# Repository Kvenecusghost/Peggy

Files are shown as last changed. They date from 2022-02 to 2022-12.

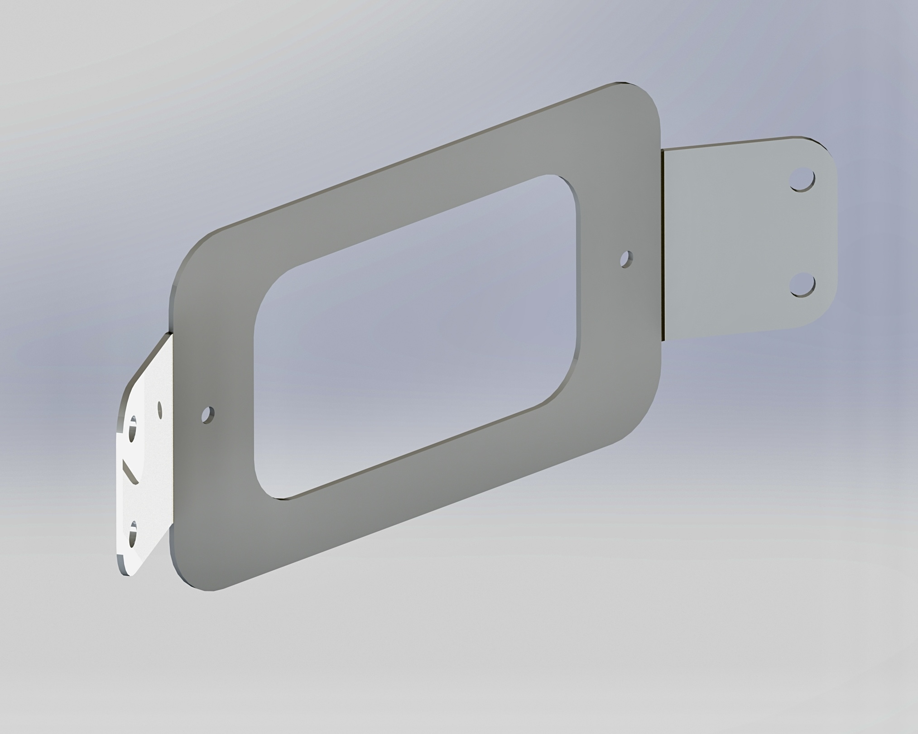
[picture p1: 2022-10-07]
Hardware_fabrication/Tracker/v2.0 19.03.2022/3d/Скриншоты/IMG_4819.JPG

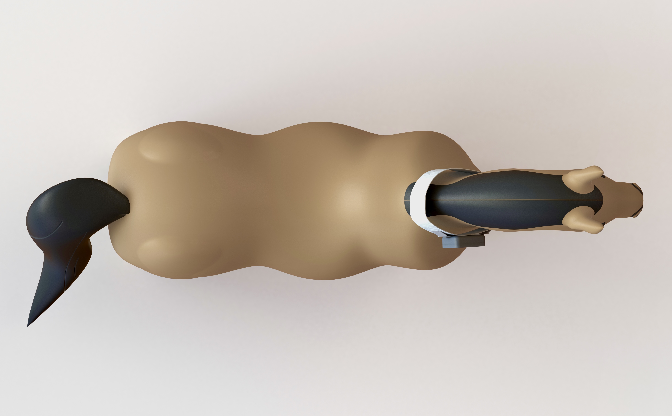
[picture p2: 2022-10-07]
Hardware_fabrication/Tracker/v2.0 19.03.2022/3d/Скриншоты/IMG_4811.JPG

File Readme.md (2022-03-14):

# Структура проекта

doc - папка для хранения документации. 

- Tracker - папка с документами для ПП трекера
- Receiver - папка с документами для ПП приёмника
- Repeater - папка с документами для ПП репитера 

Hardware - папка для хранения исходных файлов проектов ПП в ПО Altium

- Tracker - папка с проектом для ПП трекера
- Receiver - папка с проектом для ПП приёмника
- Repeater - папка с проектом для ПП репитера 

Hardware_release - папка для хранения выходных документов ПП.

- Tracker - папка с производственными файлами для ПП трекера   
- Receiver - папка с производственными файлами для ПП приёмника
- Repeater - папка с производственными файлами для ПП репитера 

   Для каждой версии создаётся отдельная папка. В названии указывается номер версии ПП и дата выгрузки файлов.
   
Software - папка с исходными файлами ПО

- Tracker - папка с исходными файлами ПО треккера Peggy

Software_release - папка скомплированных прошивок

- Tracker - папка скомпилированных прошивок для треккера Peggy
- Receiver - папка скомпилированных прошивок для приёмника Peggy
- Repeater - папка скомпилированных прошивок для репитера Peggy

   Для каждой версии создаётся отдельная папка. В названии указывается номер версии ПО и дата компиляции.

3d - папка для 3d моделей, чертежей и других файлов для корпусирования

- Tracker - папка для корпусов треккера Peggy
- Receiver - папка для корпусов приёмника Peggy
- Repeater - папка для корпусов передатчика Peggy

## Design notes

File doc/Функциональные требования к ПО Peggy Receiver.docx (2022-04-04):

# 1 ВВЕДЕНИЕ

Peggy Receiver создаётся для получения геолокационных данных о местоположении крупного скота во время выпаса.

## 1.1 Назначение данного документа

Данный документ определяет требования к встраиваемому программному обеспечению системы Peggy Receiver, для исключения ошибок проектирования программного обеспечения, которые могут вызвать систематические отказы. Данный документ является входной информацией для документов «Архитектура программного обеспечения», «Описание программного обеспечения» и для непосредственной реализации программного обеспечения.

## 1.2 Термины, определения и сокращения

Встраиваемое программное обеспечение - программное обеспечение, непосредственно реализующее функции управления устройством, как правило, записанное в энергонезависимое ПЗУ устройства и заменяемое с помощью специальных программно-аппаратных средств.

ПО – программное обеспечение.

МК – микроконтроллер.

ТЗ – техническое задание.

ЦСМ – централизованная система мониторинга.

## 1.3 Рекомендации к ознакомлению

Перед ознакомлением данного документа рекомендуется изучить техническое задание (Техническое задание Peggy Receiver) и технический проект (Технический проект Peggy Receiver) на устройство Peggy Receiver, а также следующие ссылки:

- RAK3172 Datasheet;

- HC-08 Datasheet;

- STM32WLE5CC Datasheet;

- STM32WLE5CC Reference Manual

## 1.4 Назначение разработки

ПО разрабатывается для RAK3172 на базе микроконтроллера STM32WLE5CC.

Структурная схема устройства Peggy Receiver представлена на рисунке 1.

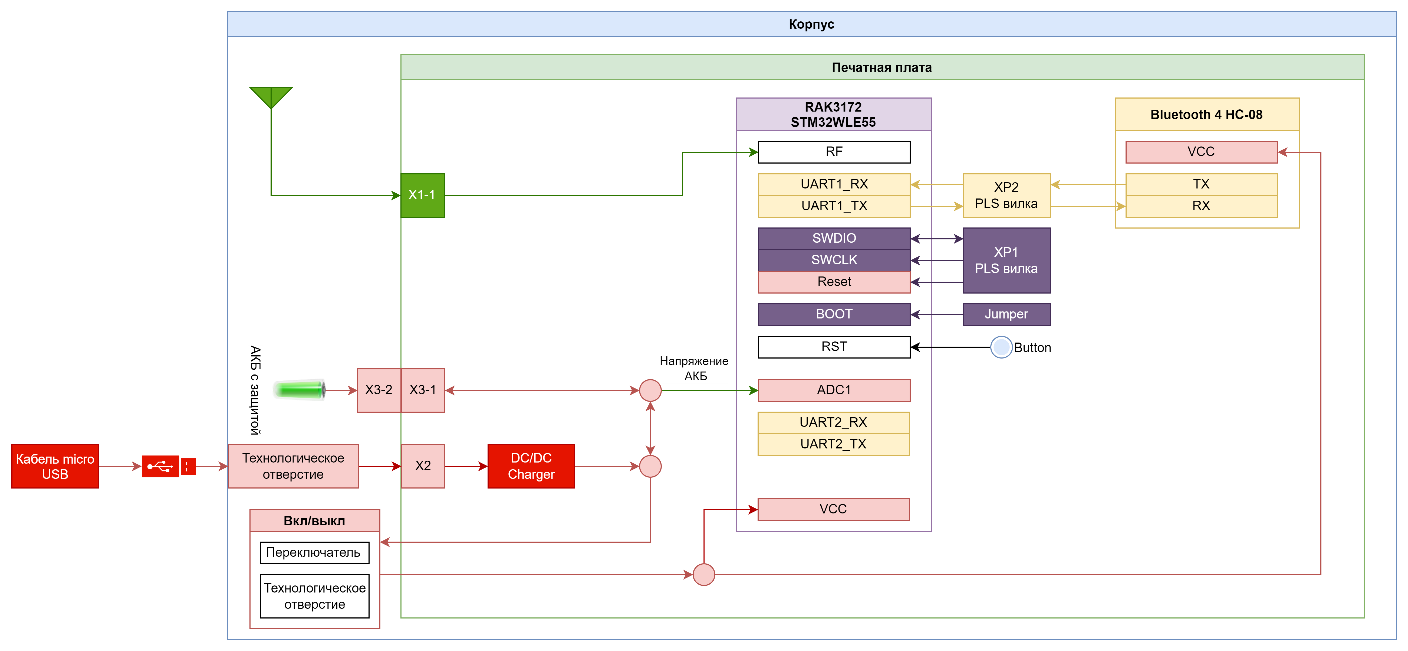
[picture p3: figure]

Рисунок 1.1 - Структурная схема устройства Peggy Receiver

МК STM32WLE5C содержит в себе ядро ARM Cortex M4 и радио интерфейс LoRa. МК содержит 256КБ Flash памяти программ и 64КБ ОЗУ, 12 битный АЦП и UART интерфейсы.

# 2 Общие характеристики устройства

Задачей системы является приём GPS координат по LoRa интерфейсу и передача данных по Bluetooth интерфейсу на смартфон. Первоначальный запуск системы осуществляется с участием человека, а дальнейшая работа происходит автоматически.

## 2.1 Функции, выполняемые устройством

Измерение заряда АКБ – заряд АКБ измеряется при помощи АЦП МК STM32WLE5CC.

Приём данных по интерфейсу LoRa – данные о местоположении принимаются по интерфейсу LoRa МК STM32WLE5CC.

Отправка данных на смартфон – отправка данных на смартфон осуществляется по интерфейсу Bluetooth.

## 2.2 Основные ограничения

1) Язык программирования C. Ограничение среды программирования применяемых МК.

## 2.3 Зависимости и влияние

Среда разработки STM32 Cube IDE или любая другая совместимая с микроконтроллерами STM32.

Для программирования МК может быть применен любой софт поддерживающий программатор ST-Link v2.

# 3 Определение требований

## 3.1 Требования к функционированию МК1

### 3.1.1 Измерение напряжения АКБ

Peggy Receiver должен иметь возможность измерять заряд АКБ. Заряд АКБ должен измеряться при помощи АЦП на порту ADC1. Отсчеты АЦП должны преобразовываться в десятые доли от максимального заряда.

### 3.1.2 Приём данных по интерфейсу LoRa

МК должен иметь возможность принимать данные по интерфейсу LoRa. В качестве полезной нагрузки должны приниматься следующие данные: уникальный ID Peggy Tracker, номер посылки, широта, долгота. Формат посылки представлен на рисунке ниже:

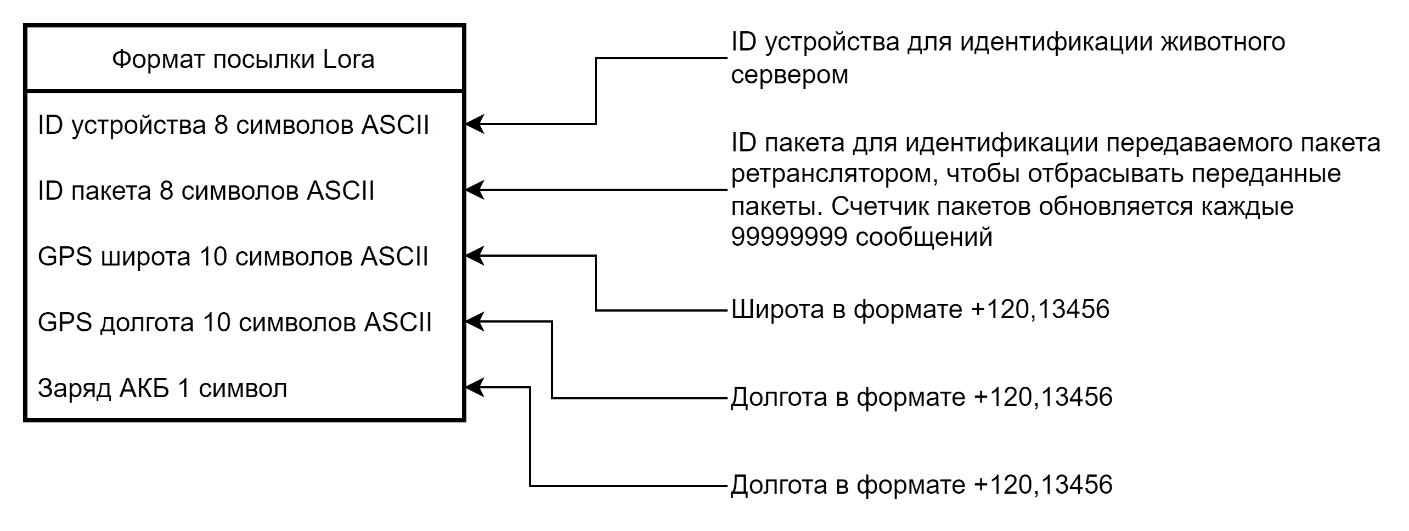
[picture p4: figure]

Рисунок 3.1. Формат посылки LoRa.

Кроме стандартных пакетов данных по интерфейсу LoRa должен приниматься пакет-тревога Peggy Tracker. Формат данной посылки представлен на рисунке ниже:

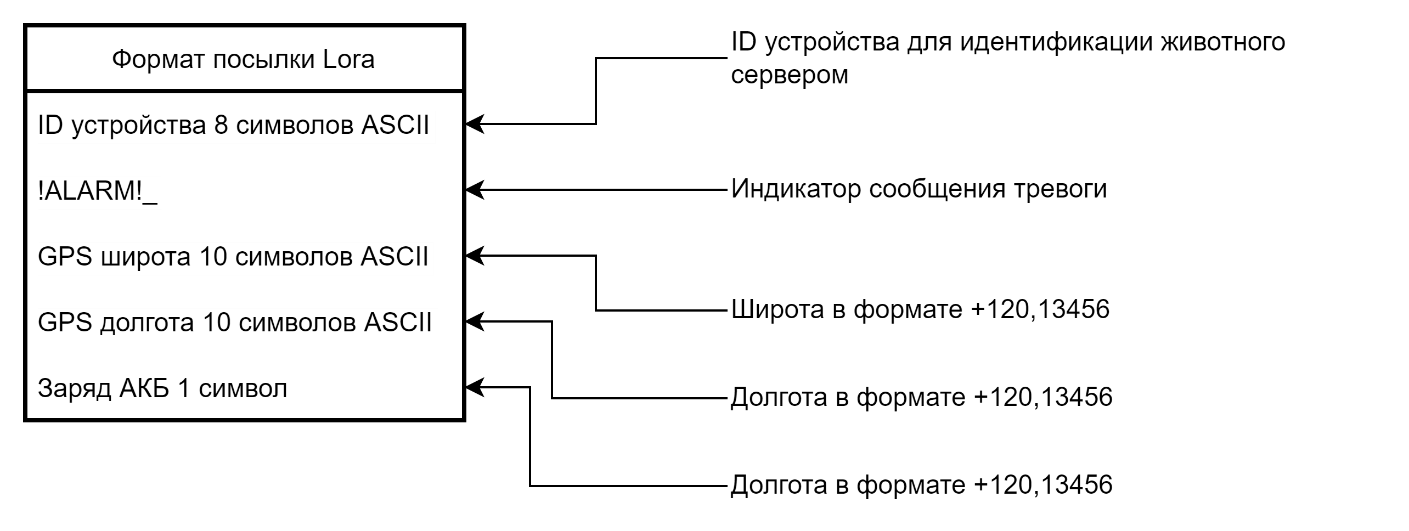
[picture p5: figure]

Рисунок 3.2. Формат посылки тревоги

## 3.2 Требования к интерфейсам

UART

Последовательный асинхронный интерфейс UART.

Интерфейс для взаимодействия с модулем HC-08.

Аналоговый вход

Интерфейс для преобразования аналоговых сигналов в цифровые. Предназначен для измерения постоянного напряжения АКБ.

Динамический диапазон входного напряжения 0~3,3В.

# 4 ЛИСТ РЕГИСТРАЦИИ ИЗМЕНЕНИЙ

№ п/п | Пункт и вносимое изменение | Ф.И.О. внесшего изменения | Подп. | Дата
1 | Инициация | Байгуаныш С. | | 04.04.2022г.

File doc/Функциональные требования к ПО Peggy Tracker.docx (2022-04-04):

# 1 ВВЕДЕНИЕ

Peggy Tracker создаётся для отслеживания геолокации крупного скота во время выпаса

## 1.1 Назначение данного документа

Данный документ определяет требования к встраиваемому программному обеспечению системы Peggy Tracker, для исключения ошибок проектирования программного обеспечения, которые могут вызвать систематические отказы. Данный документ является входной информацией для документов «Архитектура программного обеспечения», «Описание программного обеспечения» и для непосредственной реализации программного обеспечения.

## 1.2 Термины, определения и сокращения

Встраиваемое программное обеспечение - программное обеспечение, непосредственно реализующее функции управления устройством, как правило, записанное в энергонезависимое ПЗУ устройства и заменяемое с помощью специальных программно-аппаратных средств.

ПО – программное обеспечение.

МК – микроконтроллер.

ТЗ – техническое задание.

ID устройства – уникальный 4-ёх байтный идентификатор устройства. ID прописывается на стадии загрузки программы в устройство и указывается на печатной плате и корпусе устройства по окончании сборки.

ЦСМ – централизованная система мониторинга.

## 1.3 Рекомендации к ознакомлению

Перед ознакомлением данного документа рекомендуется изучить техническое задание (Техническое задание Peggy Tracker) и технический проект (Технический проект Peggy Tracker) на устройство Peggy Tracker, а также следующие ссылки:

- RAK3172 Datasheet;

- u-blox M8C Datasheet;

- STM32WLE5CC Datashet;

- STM32WLE5CC Reference Manual

## 1.4 Назначение разработки

ПО разрабатывается для RAK3172 на базе микроконтроллера STM32WLE5CC.

Структурная схема устройства Peggy Tracker представлена на рисунке 1.

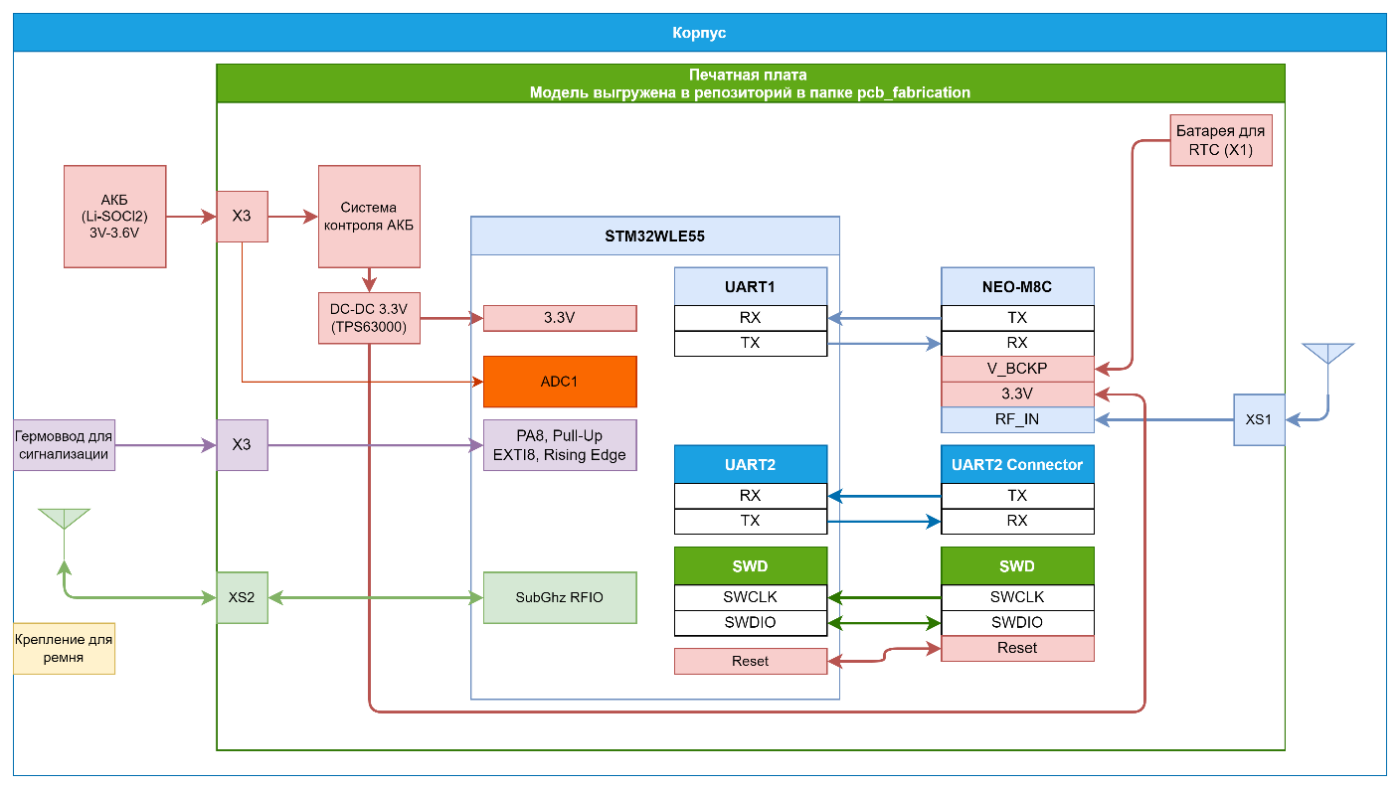
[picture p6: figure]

Рисунок 1.1 - Структурная схема устройства Peggy Tracker

МК STM32WLE5C содержит в себе ядро ARM Cortex M4 и радио интерфейс LoRa. МК содержит 256КБ Flash памяти программ и 64КБ ОЗУ, 12 битный АЦП и UART интерфейсы.

# 2 Общие характеристики устройства

Задачей системы является фиксация GPS координат и отправка по LoRa интерфейсу. Первоначальный запуск системы осуществляется с участием человека, а дальнейшая работа происходит автоматически.

## 2.1 Функции, выполняемые устройством

Измерение заряда АКБ – заряд АКБ измеряется при помощи АЦП МК STM32WLE5CC.

Сигнализация – обнаружение нарушения целостности ошейника.

Геолокация – производится при помощи модуля NEO-M8C. МК STM32WLE5CC должен считывать данные о геопозиции из модуля NEO-M8C по интерфейсу UART1.

Отправка данных по LoRa – данные о местоположении должны быть отправлены по LoRa интерфейсу.

## 2.2 Основные ограничения

1) Язык программирования C. Ограничение среды программирования применяемых МК.
2) Определение местоположения с точностью до 100м на открытой местности.

## 2.3 Зависимости и влияние

Среда разработки STM32 Cube IDE или любая другая совместимая с микроконтроллерами STM32.

Для программирования МК может быть применен любой софт поддерживающий программатор ST-Link v2.

# 3 Определение требований

1) Программный код должен гарантированно выполняться за определённое время.
1) Необходимо обеспечить отправку данных с возможностью изменения периода передачи
2) Необходимо обеспечить минимальное энергопотребление микроконтроллером и модулем NEO M8C.

## 3.1 Требования к функционированию МК

### 3.1.1 Измерение напряжения АКБ

Peggy Tracker должен иметь возможность измерять заряд АКБ. Заряд АКБ должен измеряться при помощи АЦП на порту ADC1. Отсчеты АЦП должны преобразовываться в десятые доли от максимального заряда.

### 3.1.2 Геолокация

Функция геолокации должна обеспечивать данные о местоположении устройства в виде координат GPS. В рамках данной функции МК должен считывать широту и долготу по UART из модуля NEO M8C. Также МК должен переводить и выводить из режима энергосбережения модуль NEO M8C.

### 3.1.3 Передача данных по интерфейсу LoRa

МК должен иметь возможность отправлять данные по интерфейсу LoRa. Данные должны отправляться в формате, обеспечивающем максимальный радиус передачи (до 10км). В качестве полезной нагрузки должны отправляться следующие данные: уникальный ID устройства, номер посылки, широта, долгота. Формат посылки представлен на рисунке ниже:


Рисунок 3.1. Формат посылки LoRa.

### 3.1.4 Сигнализация

Порт PA8 МК подключен к питанию через подтягивающий резистор. Когда ошейник застегнут на шее животного порт PA8 подключается к нулю при помощи интегрированного в ошейник кабеля. МК должен выходить из режима сна и отправлять сообщение по интерфейсу LoRa с тревогой, если на ножке PA8 появится высокий уровень напряжения. Формат посылки представлен на рисунке ниже:


Рисунок 3.2. Формат посылки тревоги

## 3.2 Требования к интерфейсам

Цифровой вход

Интерфейс для получения бинарной информации от внешних устройств (Сигнализация).

Время обработки информации не более одного цикла программы.

Наличие чётких логических уровней.

UART

Последовательный асинхронный интерфейс UART.

Интерфейс для взаимодействия с модулем NEO M8C.

Аналоговый вход

Интерфейс для преобразования аналоговых сигналов в цифровые. Предназначен для постоянного напряжения АКБ.

Динамический диапазон входного напряжения 0~3,3В.

# 4 ЛИСТ РЕГИСТРАЦИИ ИЗМЕНЕНИЙ

№ п/п | Пункт и вносимое изменение | Ф.И.О. внесшего изменения | Подп. | Дата
1 | Инициация | Байгуаныш С. | | 01.04.2022г.

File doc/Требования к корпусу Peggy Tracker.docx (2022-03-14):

# Технические требования к корпусу изделия Peggy Tracker

## Состав изделия

Изделие состоит из следующих частей:

- ошейник с креплением для корпуса;
- корпус;
- аккумуляторная батарея;
- печатная плата.

## Конструктивные требования к корпусу с ошейником

Общие требования к внешнему виду устройства: устройство небольших размеров с компактным дизайном корпуса, корпус должен быть обтекаемым, без заостренных углов, так как по условиям ТЗ будет плотно прилегать к телу животного (лошади), за счет чего устройство держит оптимальную температуры для работы, также корпус должен быть удобным в исполнений и использовании, пример рис. 1 и 2.

При этом должны учитываться следующие требования:

- максимальные габаритные размеры (ШхДхГ): 100х100х25 мм.;
- исполнение моноблочное с возможностью открытия (для смены батареи) с креплением на ошейник;
- эргономика: наглядность и понятность функциональных частей, удобство использования устройства;
- цветофактурное решение: гладкая поверхность, темные тона;
- требуется прочный пластик, пример ABS;
- вес не более 1,5 кг;
- ширина ошейника не более 100 мм.;
- устройство должно быть защищено от пыли и влаги по стандарту IP68;
- аппаратура должна обладать высокой противокоррозионной стойкостью;
- в течение периода его эксплуатации не должно быть коррозионных повреждений, приводящих к снижению тактико-технических характеристик;
- устройство должно быть устойчиво к ударам и тряске.

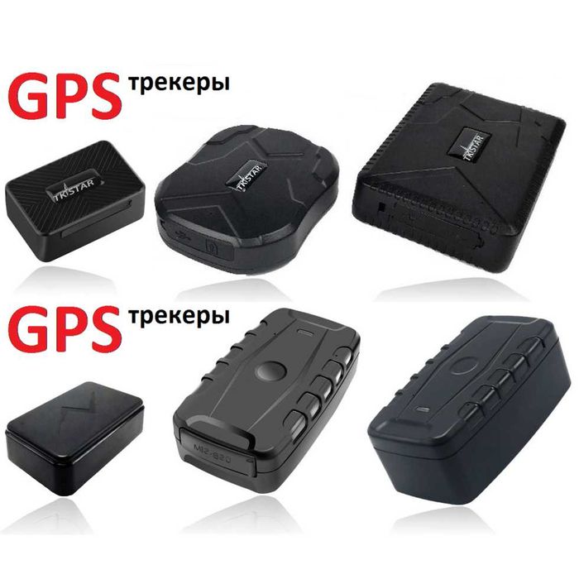
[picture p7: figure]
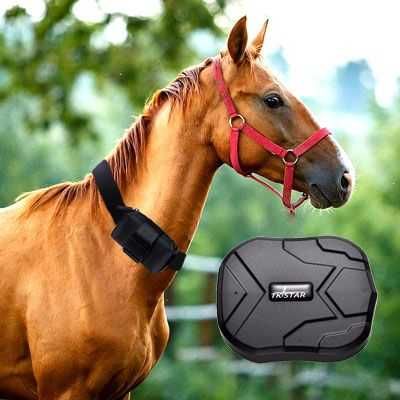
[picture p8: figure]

Рис. 1 – Пример GPS датчика | Рис. 2 – Пример крепления GPS датчика с ошейником на лошади

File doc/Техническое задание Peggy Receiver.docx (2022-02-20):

СОДЕРЖАНИЕ

# 1 НАИМЕНОВАНИЕ, ОСНОВАНИЕ, РАЗРАБОТЧИК И СРОК РАЗРАБОТКИ

1.1 Приёмнику системы отслеживания геолокации лошадей присваивается рабочее название Peggy Receiver
1.2 Принятые сокращения:

МК – микроконтроллер

АКБ – аккумуляторная батарея

ЦСМ – центральная система мониторинга

ЗУ – зарядное устройство

# 2 ЦЕЛЬ РАЗРАБОТКИ, НАИМЕНОВАНИЕ И ОБЛАСТЬПРИМЕНЕНИЯ

2.1 Цель разработки: обеспечение доставки данных о геолокации лошадей.
2.2 Полное наименование разработки – «Приёмник системы отслеживания геолокации лошадей Peggy Receiver» (далее по тексту «Peggy Receiver»).
2.3 Peggy Receiver предназначен для приёма сообщений получаемых от Peggy Tracker по интерфейсу LoRa и отправки данных на смартфон пользователя.
2.4 Областью применения Peggy Receiver являются коневодческие пастбища со свободным выгоном.

# 3 ТЕХНИЧЕСКИЕ ТРЕБОВАНИЯ

# 3.1 Состав изделия

3.1.1 В состав Peggy Receiver в общем случае должны входить:

- Плата Peggy Receiver;

- Корпус Peggy Receiver;

- АКБ;

- ЗУ;

- Паспорт Peggy Receiver.

# 3.2 Требования назначения

3.2.1 Peggy Receiver должен быть разработан для коневодческих пастбищ со свободным выгоном не оснащенным источниками электрического тока.
3.2.2 Peggy Receiver должен включать:

а) Блок микроконтроллера (БМК) – предназначенный для:

- Взаимодействия с блоком связи дальнего действия (БСДД);

- Взаимодействие с блоком связи ближнего действия (БСБД);

- Хранение базы принятых сообщений;

- Работы часов реального времени;

б) Блок связи дальнего действия – предназначенный для приёма данных о геолокации по беспроводному каналу LoRa.

в) Блок связи ближнего действия – предназначен для взаимодействия со смартфоном пользователя.

г) Блок управления питанием (БУП)– предназначенный для:

- Обеспечения питанием всех блоков ЛВМ;

- Управления зарядом/разрядом АКБ.

3.2.3 Упрощенная структурная схема Peggy Receiver приведена в приложении А.

# 3.3 Требования к функциональной совместимости

3.3.1 Peggy Receiver должен быть совместим с системой отслеживания местоположения лошадей Peggy.
3.3.2 Корпус Peggy Receiver должен иметь небольшие габариты для обеспечения мобильности.
3.3.3 Peggy Receiver должен иметь возможность заряжаться от ЗУ через разъём стандарта micro-USB.
3.3.4 Peggy Receiver должен иметь СИД для индикации включения и процесса передачи пакетов LoRa.
3.3.5 В качестве радио модуля дальнего действия должен быть использован модуль RAK3172 с рабочей частотой 868МГц.
3.3.6 В качестве радио модуля ближнего действия должен быть использован модуль совместимый со стандартом Bluetooth 4.2 и выше.
3.3.7 Радиообмен сигналами может происходить в открытом виде.

# 3.4 Требования стойкости к внешним воздействиям

3.4.1 По воздействию климатических факторов при эксплуатации Peggy Receiver, должен относиться к классу, в соответствии с Таблицей 1, и быть устойчивым к воздействию климатических факторов в соответствии с ГОСТ 15150-69.

Таблица 1– Классификация оборудования по климатическим факторам

Наименование оборудования | Климатическое исполнение по ГОСТ 15150 | Виды и нормы воздействий климатических факторов
| | Верхнее значение рабочей температуры, С | Верхнее значение предельной рабочей температуры, С | Нижнее значение рабочей температуры, С | Нижнее значение предельной рабочей температуры, С | Характер изменения температуры предельной рабочей | Верхнее значение относительной влажности воздуха, % при температуре 25°С
Peggy Receiver | ТпПр1 | +50 | +60 | -10 | -10 | Постепенное | 98

3.4.2 Peggy Receiver должен быть устойчивым к воздействию механических нагрузок в соответствии с таблицей 2.

Таблица 2 – Классификация оборудования по механическим факторам

Наименование оборудования | Диапазон частот, Гц | Виды и нормы воздействий механических факторов
| | Вибрация
| | Амплитудное значение ускорения, м/с, в направлении воздействия
| | Вертикальном | Горизонтальном
Peggy Receiver | 1-55 | 2 | 2

3.4.3 Степень защиты, обеспечиваемая корпусом, по ГОСТ 14254– не менее IP54.
3.4.4 Peggy Receiver должен быть стойким к воздействию электромагнитных помех с критерием функционирования «B» и соответствовать ГОСТ 30804.6.1.

# 3.5 Требования надежности, готовности и ремонтопригодности

3.5.1 Средняя наработка Peggy Receiver (включая ПО) на отказ не менее 48ч (2 дня) непрерывной работы.
3.5.2 Peggy Receiver должен функционировать в непрерывном длительном режиме.
3.5.3 Средний срок службы до списания не менее 10 лет.
3.5.4 Среднее время восстановления работоспособного состояния не более 40 мин.

# 3.6 Требования безопасности

# 3.6.1 Требования к электробезопасности

3.6.1.1 По электробезопасности оборудование Peggy Receiver должен относиться к II классу по ГОСТ МЭК 61140.
3.6.1.2 Электрическая изоляция электрических цепей Peggy Receiver должна соответствовать требованиям ГОСТ Р МЭК 60664.1-2012.
3.6.1.3 Peggy Receiver должен эксплуатироваться в соответствии с «Правилами техники безопасности при эксплуатации электроустановок потребителем».

# 3.6.2 Требования к функциональной безопасности

3.6.2.1 Требования к функциональной безопасности не предъявляются.

# 3.6.3 Требования к пожарной безопасности

3.6.3.1 Применяемые материалы должны быть трудногорючими по ГОСТ 12.1.044.
3.6.3.2 Уровень обеспечения пожарной безопасности людей в соответствии с п.1.2 ГОСТ 12.1.004.

# 3.7 Требования эргономики и технической эстетики

    3.7.1 Эргономика и техническая эстетика Peggy Receiver должна соответствовать ГОСТ 20.39.108.
    3.7.2 Peggy Receiver должен работать в полностью автоматическом режиме. Обслуживающий персонал должен участвовать только в устранении неисправностей и отказов.
    3.7.3 Конструкция Peggy Receiver должна обеспечивать удобный монтаж.
    3.7.4 Устройства визуального контроля должны обеспечивать четкое и однозначное восприятие информации обслуживающим персоналом.
    3.7.5 Надписи должны иметь хорошо читаемые символы и быть контрастными.
    3.7.6 Металлические детали должны иметь защитные антикоррозионные покрытия (за исключением деталей, выполняющих функцию теплоотвода).
    3.7.7 Металлические детали, не имеющие гальванических покрытий, должны иметь лакокрасочные покрытия.

# 3.8 Требования к эксплуатации, хранению, удобству технического обслуживания и ремонта

# 3.8.1 Требования к условиям эксплуатации

  3.8.1.1 Технически Peggy Receiver должен быть реализован без использования оборудования, требующего регулярной периодической замены.
  3.8.1.2 Окружающая среда не взрывоопасная.
  3.8.1.3 Гарантийный срок эксплуатации Peggy Receiver должен быть не менее 1 года.

# 3.8.2 Требования к хранению

  3.8.2.1 Условия хранения должны соответствовать в части воздействия климатических факторов «5» (ОЖ4) по ГОСТ 15150.
  3.8.2.2 Гарантийный срок хранения 1 год.

# 3.8.3 Требования к техническому обслуживанию

  3.8.3.1 БМК должен иметь выводы для подключения к нему программатора внутри корпуса.
  3.8.3.2 БМК должен иметь выводы, позволяющие сбросить Peggy Receiver на настройки по умолчанию.
  3.8.3.3 БМК должен иметь собственные часы реального времени.
  3.8.3.4 БМК должен иметь встроенные источники электроэнергии для питания часов реального времени, рассчитанные на весь срок службы Peggy Receiver.

# 3.8.4 Требование к ремонтопригодности

  3.8.4.1 На месте эксплуатации Peggy Receiver должен восстанавливаться путем замены на новый.

# 3.9 Требования транспортабельности

3.9.1 Условия транспортирования должны соответствовать в части воздействия:

- механических факторов – группе «Ж» по ГОСТ 23216;

- климатических факторов – группе «5» (ОЖ4) по ГОСТ 15150.

# 3.10 Требования безопасности и охраны здоровья

  3.10.1 Общие требования безопасности должны соответствовать ГОСТ 12.2.007.0.
  3.10.2 При производстве должны выполняться требования техники безопасности по ГОСТ 12.3.008.
  3.10.3 Обеспечение специальной защитной одеждой, средствами индивидуальной защиты ног (специальная обувь) и другими предохранительными средствами согласно требованиям ГОСТ 12.4.011 и ГОСТ 12.4.103.
  3.10.4 Санитарно-гигиенические требования рабочей зоны должны соответствовать ГОСТ 12.1.005.
  3.10.5 Общие требования пожарной безопасности в производственных помещениях должны соответствовать Техническому регламенту «Общие требования к пожарной безопасности» и ГОСТ 12.1.004.

# 3.11 Требования стандартизации, унификации и каталогизации

  3.11.1 Комплектующие изделия Peggy Receiver должны быть серийно производимые.
  3.11.2 Должна быть разработана карта замены, допускающая замену элементов одной серии или производителя на изделия другой серии или производителя.

# 3.12 Требования технологичности

  3.12.1 Обеспечить технологичность Peggy Receiver в соответствии с ГОСТ 14.201.
  3.12.2 Запуск Peggy Receiver должен производиться в соответствии с разработанным технологическим процессом запуска на Peggy Receiver.

# 3.13 Конструктивные требования

  3.13.1 Конструкция Peggy Receiver должна обеспечивать:

- удобство эксплуатации изделия;

- индикацию работоспособности в процессе эксплуатации.

# 3.14 Требования охраны окружающей среды

  3.14.1 Контроль вредных выбросов при производстве Peggy Receiver должен производиться по ГОСТ 17.2.3.02.
  3.14.2 ПДК загрязняющих веществ в атмосферном воздухе должно быть в соответствии с ГН 2.1.6.1338-03.

# 3.15 Требования к утилизации

  3.15.1 Перед утилизацией производится разукомплектование и демонтаж комплектующих изделий в соответствии с ведомостью оценки и технического состояния, представляемой вместе с актом на списание.
  3.15.2 После снятия с эксплуатации, изделия не представляют опасности для жизни, здоровья людей и окружающей среды.
  3.15.3 Утилизация по ГОСТ Р 53692.

# 4 ТЕХНИКО-ЭКОНОМИЧЕСКИЕ ТРЕБОВАНИЯ

4.1 Себестоимость Peggy Receiver не должна превышать 50000тг.
4.2 Предполагаемый объем выпуска не менее 10шт.
4.3 Экономический эффект достигается за счет сокращения фактов хищения и утери лошадей.

# 5 ТРЕБОВАНИЯ К ВИДАМ ОБЕСПЕЧЕНИЯ

# 5.1 Требования к метрологическому обеспечению

  5.1.1 В качестве средств измерений и контроля параметров при проверке должны использоваться средства измерений и контроля общего применения.
  5.1.2 Должен быть разработан перечень средств измерений и контроля.
  5.1.3 Годность указанных средств должна быть подтверждена сопроводительными документами или клеймами, и они должны быть аттестованы или поверены в установленном порядке.

# 5.2 Требования к диагностическому обеспечению

  5.2.1 Должна производиться диагностика и контроль следующих параметров:

- уровень заряда АКБ

- сообщения за последние 24 часа

  5.2.2 Peggy Receiver должен иметь возможность принимать данные по беспроводному интерфейсу LoRa.
  5.2.3 В Peggy Receiver должна быть возможность смены радиоканалов.
  5.2.4 Полученный пакет должен отправляться в смартфон по Bluetooth интерфейсу не позже, чем через 2 секунды.

# 5.3 Требования к нормативно-техническому обеспечению

  5.3.1 На Peggy Receiver должна быть разработана следующая документация:

- принципиальные схемы;

- монтажные схемы;

- руководство по эксплуатации;

- сводная ведомость;

- методика испытаний;

- программная документация;

Документация должна быть выполнена на русском языке.

# 5.4 Требования к математическому, программному и информационно-лингвистическому обеспечению

  5.4.1 Для БМК в составе Peggy Receiver необходимо разработать встраиваемое программное обеспечение.
  5.4.2 Программное обеспечение БМК в составе Peggy Receiver должно соответствовать ГОСТ Р 51904.
  5.4.3 К встраиваемому программному обеспечению предъявляются следующие требования:

- цикл разработки и документирование ПО должен осуществляться по ГОСТ Р 51904;

- должны быть произведены испытания программного обеспечения.

  5.4.4 Вся представляемая и выводимая информация должна быть на русском языке.

# 6 ТРЕБОВАНИЯ К СЫРЬЮ, МАТЕРИАЛАМ И КОМПЛЕКТУЮЩИМ ИЗДЕЛИЯМ

6.1 Применяемые комплектующие изделия и материалы должны быть допущены к применению на территории стран Таможенного союза.
6.2 Подлежащие обязательной сертификации комплектующие изделия и материалы должны иметь действующие на территории стран Таможенного союза сертификаты.

# 7 ТРЕБОВАНИЯ К МАРКИРОВКЕ И УПАКОВКЕ

7.1 Маркировка и упаковка Peggy Receiver должна соответствовать ТР ТС 003/2011.
7.2 На внешней стороне Peggy Receiver должна быть наклеена самоклеящаяся этикетка, в которой на государственном и русском языках должны быть указаны:

- наименование Peggy Receiver;

- наименование и (или) товарный знак предприятия-изготовителя;

- класс защиты от поражения электрическим током;

- заводской номер Peggy Receiver;

- дата изготовления (месяц и год изготовления);

- надпись «Сделано в Республике Казахстан».

7.3 Маркировка должна быть разборчивой, легко читаемой.
7.4 Маркировка не должна осыпаться, расплываться и выцветать в течение всего срока эксплуатации.
7.5 Транспортная маркировка должна соответствовать ГОСТ 14192.
7.6 На упаковку должна быть наклеена самоклеящаяся этикетка, на которой на государственном и русском языках должны быть указаны:

- наименование Peggy Receiver;

- товарный знак предприятия-изготовителя;

- наименование предприятия-изготовителя;

- юридический адрес предприятия-изготовителя;

- обозначение нормативного документа, в соответствии с которым произведен Peggy Receiver;

- заводской номер Peggy Receiver;

- дата изготовления (месяц и год изготовления);

- масса брутто/нетто в килограммах;

- надпись «Сделано в Республике Казахстан».

7.7 Упаковка должна обеспечивать сохранность при транспортировке и хранении. Упаковку разработать в соответствии с ГОСТ 23216 и требованиями п.3.9 настоящего технического задания.

# 8 ТРЕБОВАНИЯ К СРЕДСТВАМ ОБУЧЕНИЯ

8.1 Так как сборка будет осуществляться силами сотрудников проекта, технологический процесс на сборку не требуется
8.2 Для обучения персонала эксплуатирующей организации должна быть разработана презентация.

# 9 СПЕЦИАЛЬНЫЕ ТРЕБОВАНИЯ

# 9.1 Требования к патентной чистоте и патентоспособности

9.1.1 Требования к патентной чистоте в отношении Peggy Receiver не предъявляются.

# 9.2 Требования разработки средств обеспечения испытаний изделия

9.2.1 Для проведения проверки работоспособности Peggy Receiver после изготовления необходимо разработать соответствующий стенд для ОТК.

# 9.3 Требования к сертификации и декларированию

9.3.1 Требований к сертификации и декларированию изделия не предъявляется.

# 10 ЭТАПЫ ВЫПОЛНЕНИЯ РАЗРАБОТКИ

10.1 Этапы разработки согласно ГОСТ Р 15.301-2016.
10.2 Должно быть изготовлено 10 образцов Peggy Receiver для проведения испытаний.
10.3 Необходимо определить место проведения эксплуатационных испытаний.
10.4 Необходимо разработать эксплуатационную документацию.
10.5 После установки и проведения полевых испытаний процесс разработки считается завершенным.

# 11 ПОРЯДОК ВЫПОЛНЕНИЯ И ПРИЕМКИ ЭТАПОВ РАЗРАБОТКИ

11.1 Порядок разработки согласно ГОСТ Р 15.301-2016.
11.2 Изготовленный образец должен пройти эксплуатационные испытания.
11.3 Разрабатываемая документация должна быть выполнена в соответствии с требованиями стандартов Единой системы конструкторской документации.
11.4 Порядок выполнения согласно таблице 3.

Таблица 3 – Порядок выполнения этапов разработки

№ | Наименование | Код
| Реестр документов | PGGRCVR.000ДР
| Техническое задание | PGGRCVR.001ТЗ
| Требования к корпусу | PGGRCVR.002ТК
| Функциональные требования к ПО | PGGRCVR.003ФПО
| Архитектура ПО | PGGRCVR.004АПО
| Технический проект | PGGRCVR.005ТП
| Электрическая принципиальная схема | PGGRCVR.006Э3
| Монтажная схема | PGGRCVR.040Э4
| Схема подключения | PGGRCVR.042Э5
| Сборочный чертеж | PGGRCVR.043СБ
| Паспорт | PGGRCVR.016ПС

# 12 ПРЕДПОЛАГАЕМЫЙ РАЗРАБОТЧИК И ПОЛИГОН ВНЕДРЕНИЯ ПРОДУКЦИИ

12.1 Разработчик Peggy Receiver – АО «КАТУ им. С.Сейфуллина
12.2 Полигон внедрения –

# ПРИЛОЖЕНИЕ А. Упрощенная структурная схема Peggy Receiver

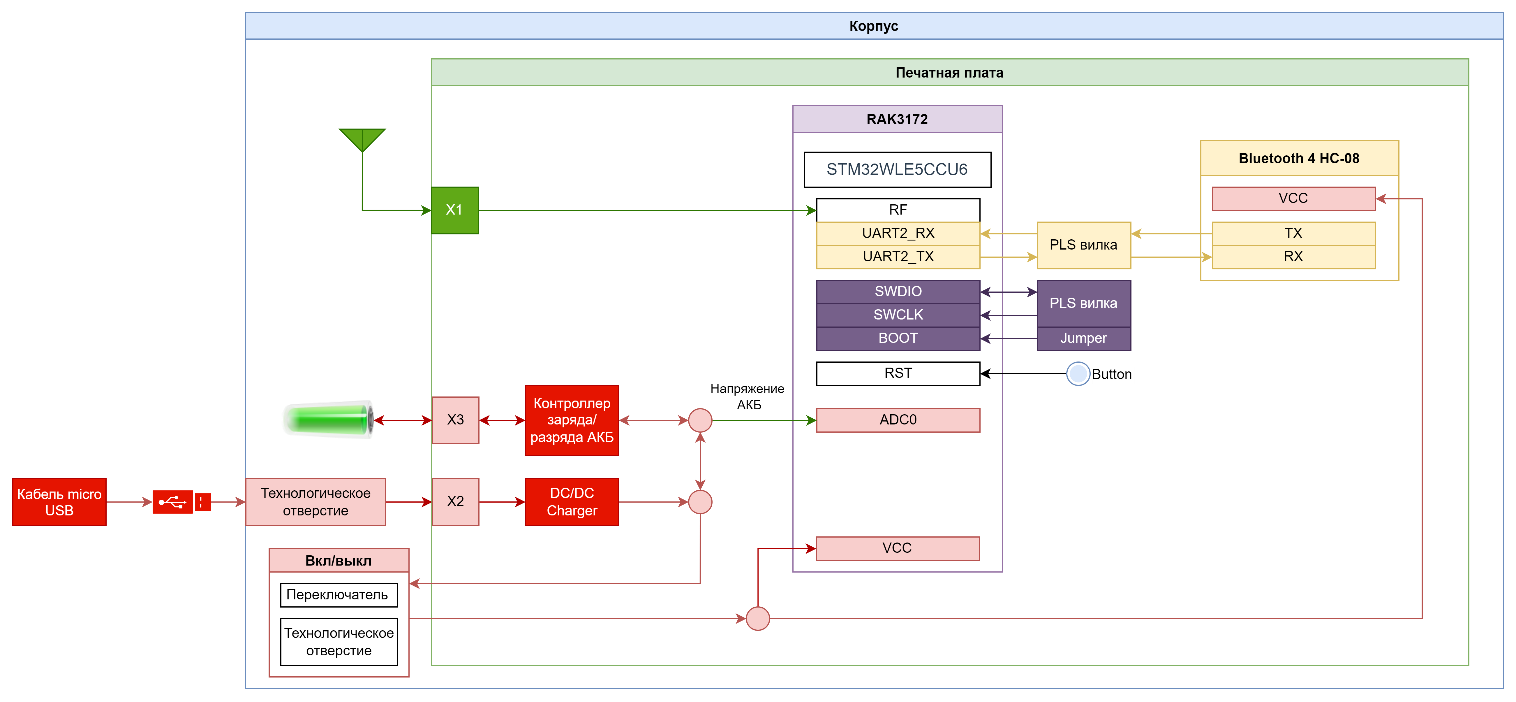
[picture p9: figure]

Рисунок А1 - Упрощенная структурная схема Peggy Receiver

# ПРИЛОЖЕНИЕ Б. Список использованной нормативной документации

1 При разработке настоящего технического задания учитывались требования следующих документов:

- ГОСТ 12.1.004-91 «Система стандартов безопасности труда. Пожарная безопасность. Общие требования»;

- ГОСТ 12.1.005-88 «Система стандартов безопасности труда. Общие санитарно-гигиенические требования к воздуху рабочей зоны»;

- ГОСТ 12.1.044-2018 «Система стандартов безопасности труда. Пожаровзрывоопасность веществ и материалов. Номенклатура показателей и методы их определения»;

- ГОСТ 12.2.007.0-75 «Система стандартов безопасности труда. Изделия электротехнические. Общие требования безопасности»;

- ГОСТ 12.3.008-75 «Система стандартов безопасности труда. Производство покрытий металлических и неметаллических неорганических. Общие требования безопасности»;

- ГОСТ 12.4.011-89 «Система стандартов безопасности труда. Средства защиты работающих. Общие требования и классификация»;

- ГОСТ 12.4.103-83 «Система стандартов безопасности труда. Одежда специальная защитная, средства индивидуальной защиты ног и рук. Классификация»;

- ГОСТ 14.201-83 «Обеспечение технологичности конструкций изделий. Общие требования»;

- ГОСТ 15.012-84 «Система разработки и постановки продукции на производство. Патентный формуляр»;

- ГОСТ 17.2.3.02-2014 «Правила установления допустимых выбросов загрязняющих веществ промышленными предприятиями»;

- ГОСТ 20.39.108-85 «Комплексная система общих технических требований. Требования по эргономике, обитаемости и технической эстетике. Номенклатура и порядок выбора»;

- ГОСТ 14192-96 «Маркировка грузов»;

- ГОСТ 14254-2015 «Степени защиты, обеспечиваемые оболочками (Код IP)».

- ГОСТ 15150-69 «Машины, приборы и другие технические изделия. Исполнения для различных климатических районов. Категории, условия эксплуатации, хранения и транспортирования в части воздействия климатических факторов внешней среды»;

- ГОСТ 18620-86 «Изделия электротехнические. Маркировка»;

-ГОСТ 23216-78 «Изделия электротехнические. Хранение, транспортирование, временная противокоррозионная защита, упаковка. Общие требования и методы испытаний»;

- ГОСТ 30804.6.1-2013 «Устойчивость к электромагнитным помехам технических средств, применяемых в жилых, коммерческих зонах и производственных зонах с малым энергопотреблением»;

- ГОСТ Р 51904-2002 «Программное обеспечение встроенных систем. Общие требования к разработке и документированию»;

- ГОСТ МЭК 61140-2012 «Защита от поражения электрическим током. Общие положения для электроустановок и электрооборудования»;

- Гигиенические нормативы ГН 2.1.6.1338-03 «Предельно допустимые концентрации (ПДК) загрязняющих веществ в атмосферном воздухе населенных мест».

# ЛИСТ РЕГИСТРАЦИИ ИЗМЕНЕНИЙ

№ п/п | Пункт и вносимое изменение | Ф.И.О. внесшего изменения | Подп. | Дата
1 | Инициация | Байгуаныш С.Б. | | 19.02.2022
2 | Вставил доработанную структурную схему | Байгуаныш С.Б. | | 20.02.2022

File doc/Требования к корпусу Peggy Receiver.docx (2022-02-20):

# Технические требования к корпусу изделия Receiver

## Состав изделия

Изделие состоит из следующих частей:

- корпус;
- аккумуляторная батарея;
- антенна;
- печатная плата.

## Конструктивные требования к корпусу Receiver

Общие требования к внешнему виду устройства: устройство небольших размеров сопоставимые с размерами мобильных устройств, корпус должен быть обтекаемым, без заостренных углов, также корпус должен быть удобным в исполнении и использовании, пример рис. 1 и 2.

При этом должны учитываться следующие требования:

- максимальные габаритные размеры (ШхДхГ): 100х150х50 мм.;
- исполнение моноблочное;
- цветофактурное решение: гладкая поверхность, темные тона;
- требуется прочный пластик, пример ABS;
- вес не более 1 кг;
- необходимо предусмотреть различные эксплуатации: в руках, стационарное;
- устройство должно быть защищено от пыли и влаги по стандарту IP68;
- аппаратура должна обладать высокой противокоррозионной стойкостью;
- в течение периода его эксплуатации не должно быть коррозионных повреждений, приводящих к снижению тактико-технических характеристик;
- устройство должно быть устойчиво к ударам и тряске.

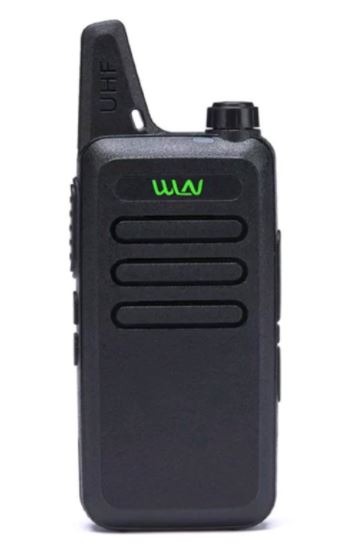
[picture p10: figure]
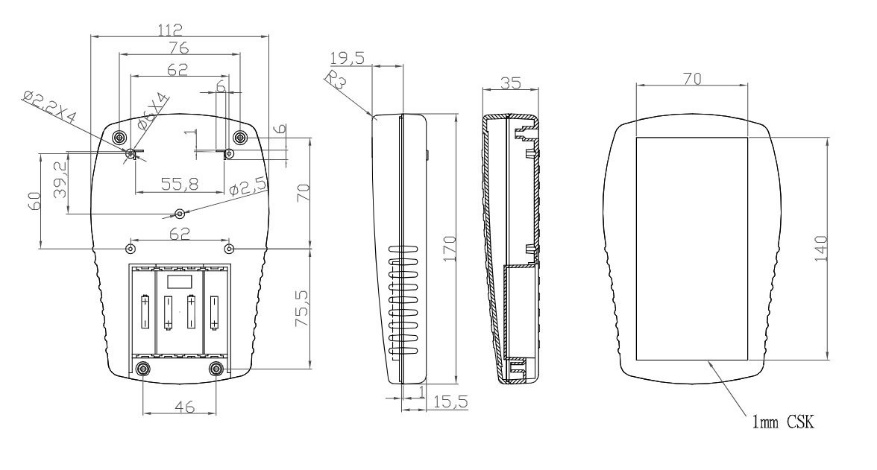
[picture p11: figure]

Рис. 1 – Пример корпуса Receiver | Рис. 2 – Пример корпуса Receiver

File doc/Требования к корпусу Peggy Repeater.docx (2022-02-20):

# Технические требования к корпусу изделия Repeater

## Состав изделия

Изделие состоит из следующих частей:

- корпус;
- антенна;
- аккумуляторная батарея;
- солнечная панель;
- печатная плата.

## Конструктивные требования к корпусу Repeater

Общие требования к внешнему виду устройства: габариты устройства зависит напрямую от выбранного АКБ, корпус должен быть прочным к внешней среде, без заостренных углов, также корпус должен быть удобным в исполнении и использовании, пример рис. 1.

При этом должны учитываться следующие требования:

- минимальные габаритные размеры (ШхДхГ): 150х200х100 мм.;
- исполнение моноблочное с возможностью открытия (для смены батареи);
- цветофактурное решение: гладкая поверхность, темные-светлые тона;
- требуется прочный пластик, пример ABS либо изготовить из металла;
- вес не более 2,5 кг;
- устройство должно быть защищено от пыли и влаги по стандарту IP68;
- аппаратура должна обладать высокой противокоррозионной стойкостью;
- в течение периода его эксплуатации не должно быть коррозионных повреждений, приводящих к снижению тактико-технических характеристик;
- устройство должно быть устойчиво к ударам и тряске.

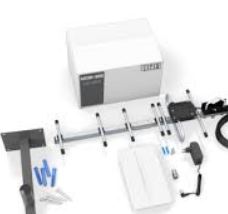
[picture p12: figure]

Рис. 1 – Пример GPS датчика

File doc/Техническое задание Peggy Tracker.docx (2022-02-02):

# Общие сведения;

Наименование: носимое автономное устройство слежения за местоположением скота.

Основание: ТЗ составлено на основе ГОСТ 15.016-2016

Исполнитель:

Сроки выполнения:

# Цель выполнения ОКР;

Цель: разработка законченного устройства слежения за местоположением скота удовлетворяющим всем предъявляемым требованиям согласно настоящему ТЗ.

Назначение: устройство предназначено для отслеживания местоположения лошадей и других животных с целью предотвращения хищения и потери скота. Предполагается применение устройства в условиях отсутствия общедоступных беспроводных сетей связи таких как GSM и Wi-Fi.

Преимущества: увеличение срока функционирования на одном заряде до 3-х месяцев.

# Технические требования к изделию

## Состав изделия

Изделие состоит из следующих частей:

- ошейник с креплением для корпуса
- корпус
- аккумуляторная батарея
- печатная плата

## Требования назначения

- Устройство должно функционировать без подзарядки в течение не менее 90 дней.
- Устройство должно передавать данные о своём местоположении с точностью до 100м на открытой местности.
- Устройство должно передавать данные о своём местоположении не реже 1-го раза в 1 час.
- Устройство должно передавать сигнал аварии в случае нарушения целостности корпуса и/или ошейника
- Устройство должно передавать сигнал аварии в случае пересечения заданных границ
- Устройство должно передавать данные в нелицензируемых частотных диапазонах

## Конструктивные требования

Устройство должно соответствовать следующим конструктивным требованиям:

- габариты не более 100х100х25mm
- исполнение моноблочное с креплением на ошейник
- ширина ошейника не менее 100mm
- вес не более 1.5кг

## Требования электромагнитной совместимости

Устройство должно обеспечивать ЭМС по ГОСТ 32134.1-2013 (Совместимость технических средств электромагнитная. ТЕХНИЧЕСКИЕ СРЕДСТВА РАДИОСВЯЗИ. Часть 1. Общие технические требования и методы испытаний).

## Требования живучести и стойкости к внешним воздействиям

Устройство должно быть защищено от пыли и влаги по стандарту IP68.

Аппаратура должна обладать высокой противокоррозионной стойкостью. В течение периода его эксплуатации не должно быть коррозионных повреждений, приводящих к снижению тактико-технических характеристик.

Устройство должно быть устойчиво к ударам и тряске

## Требования надежности

Согласно ГОСТ 27.003 изделие должно соответствовать изделием конкретного назначения (ИКН), вида I, восстанавливаемое.

## Требования эргономики, обитаемости и технической эстетики

## Требования к эксплуатации, хранению, удобству технического обслуживания и ремонта

Устройство должно функционировать не менее 90 дней в автономном режиме.

Устройство должно подавать сигнал в случае нарушения его целостности.

Устройство должно обслуживаться одним человеком.

Устройство должно снабжаться паспортом и инструкцией пользователя.

## - транспортирование;

## - требования безопасности;

## - требования стандартизации, унификации и каталогизации;

## - требования технологичности;

## - конструктивные требования.

# - технико-экономические требования;

# - требования к видам обеспечения;

# - требования к сырью, материалам и КИМП;

# - требования к консервации, упаковке и маркировке;

# - требования к учебно-тренировочным средствам (при необходимости);

# - специальные требования;

# - требования к документации;

# - этапы выполнения ОКР;

# - порядок выполнения и приемки этапов ОКР.

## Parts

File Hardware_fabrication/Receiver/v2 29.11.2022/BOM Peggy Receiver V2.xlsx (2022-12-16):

 | Peggy Receiver.PrjPcb
 | Set: | 1
# | Designator | Description | Name | Footprint | Supplier 1 | Supplier Part Number 1 | Manufacturer Part Number 1 | Manufacturer 1 | Quantity | Total Quantity | Supplier Stock 1 | Supplier Unit Price 1 | Total Price
1 | C1, C7, C8, C9, C10 |  | 0.1uF | CH0603C | Digi-Key | 490-4779-1-ND | GCM188R71H104KA57D | Murata | 5 | 5 | 17132976 | 0.11 | 0.55
2 | C2, C3 | 0603 50V C0G 27pF 5% multilayer ceramic capacitor | CC0603JPNPO9BN270 | CAPC1608X87X35NL15T15 | Digi-Key | 13-CC0603JPNPO9BN270DKR-ND | CC0603JPNPO9BN270 | Yageo | 2 | 2 | 20149 | 0.1 | 0.2
3 | C4, C5, C6, C11, C12, C13 | CAP CER 10UF 16V X7R 1206 | 10uF | CH1206C | Digi-Key | 490-14746-1-ND | GCM31CR71C106KA64K | Murata | 6 | 6 | 65503 | 0.41 | 2.46
4 | C14 |  | 1uF | CH0603C | Digi-Key | 1276-1946-1-ND | CL10B105KP8NNNC | Samsung | 1 | 1 | 10471004 | 0.1 | 0.1
5 | D1 | Bluetooth 4.0 module | HC-08 | MOD: SH-HC-08 | Aliexpress | https://aliexpress.ru/item/32817019978.html?sku_id=10000014391676369 | ЦветHC-08 with Board |  | 1 | 1 |  | 5 | 5
6 | D2 | Li-ion chargers | MCP73831T-2ATI/OT | SOT23-5 | Digi-Key | MCP73831T-2ATI/OTCT-ND | MCP73831T-2ATI/OT | Microchip | 1 | 1 | 47125 | 0.76 | 0.76
7 | DD1 | RF TXRX MODULE ISM<1GHZ | RFM95W-868S2 | RFM95W-868S2 | Aliexpress | https://aliexpress.ru/item/32810607598.html?sku_id=65554951845 | RFM95W-868S2 | RF Solutions | 1 | 1 |  | 5 | 5
8 | GB1 |  | 1-12 шт., перезаряжаемые литий-полимерные аккумуляторы 3,7 в, 1260100 мАч | BAT: 34.5X52MM (only pads) | Aliexpress | https://aliexpress.ru/item/1005002756145305.html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 |  |  | 1 | 1 |  | 10 | 10
9 | GB2 | LiPo Battery | LP103450JH+PCM+PTC+2 WIRES 70MM | BAT: 34.5X52MM | Digi-Key | 1908-LP103450JH+PCM+PTC+2WIRES70MM-ND | LP103450JH+PCM+PTC+2WIRES70MM | Jauch | 1 | 1 | 2266 | 17.33 | 17.33
10 | HL1 | WURTH ELEKTRONIK - 150060GS75000 - LED, Green, 520 nm, 3.2 V, 30 mA, 430 mcd RoHS Compliant: Yes | 150060GS75000 | CH0603LG | Digi-Key | 732-4971-6-ND | 150060GS75000 | Wurth Electronics | 1 | 1 | 181963 | 0.15 | 0.15
11 | J1 | Jumper | Jumper-2 | CON: JUMPER_2 |  |  |  |  | 1 | 1 |  |  | 0
12 | L1, L2, L3 | Ferrite Beads High Current Chip 470Ohm 25% 100MHz 1A 0.2Ohm DCR 0805 T/R | MH2029-471Y | MH2029-471Y-Footprint-1 | Digi-Key | 118-MH2029-471YDKR-ND | MH2029-471Y | Bourns | 3 | 3 | 14551 | 0.1 | 0.3
13 | MPU1 | 8-bit Microcontroller with 32 Kbytes of ISP Flash and USB Controller, 2.7 to 5.5 V, -40 to 85 degC, 44-Pin QFP, Tray | ATMEGA32U4-AU | ATMEGA32U4-MU | Digi-Key | ATMEGA32U4-AU-ND | ATMEGA32U4-AU | Microchip / Atmel | 1 | 1 | 44865 | 5.68 | 5.68
14 | R1 | Res Thick Film 0603 4.7K Ohm 1% 1/10W 100ppm/C Molded SMD SMD Paper T/R | RMCF0603FT4K70 | CH0603R | Digi-Key | RMCF0603FT4K70DKR-ND | RMCF0603FT4K70 | Stackpole Electronics | 1 | 1 | 7496694 | 0.1 | 0.1
15 | R2, R8, R9 |  | 1k | CH0603R | Digi-Key | 311-1.00KHRCT-ND | RC0603FR-071KL | Yageo | 3 | 3 | 30608346 | 0.021 | 0.063
16 | R3 | Chip Resistor, 100 KOhm, +/- 1%, 0.1 W, -55 to 155 degC, 0603 (1608 Metric) | Resistor 100k +/-1% 0603 100 mW | RESC1608X55X25NL10T15 | Digi-Key | 311-100KHRCT-ND | RC0603FR-07100KL | Yageo | 1 | 1 | 14314617 | 0.1 | 0.1
17 | R4 | RES 3.6K OHM 1% 1/10W 0603 | 3.6K | CH0603R | Digi-Key | 311-3.60KHRCT-ND | RC0603FR-073K6L | Yageo | 1 | 1 | 560651 | 0.1 | 0.1
18 | R5, R7 | RES 22 OHM 1% 1/10W 0603 | 22 | CH0603R | Digi-Key | 311-22.0HRCT-ND | RC0603FR-0722RL | Yageo | 2 | 2 | 4946551 | 0.1 | 0.2
19 | R6 | 510 Ohms ±5% 0.1W, 1/10W Chip Resistor 0603 (1608 Metric) Automotive AEC-Q200 Thick Film | RMCF0603JT510R | RESC1608X55X25NL10T15 | Digi-Key | RMCF0603JT510RCT-ND | RMCF0603JT510R | Stackpole Electronics | 1 | 1 | 174797 | 0.1 | 0.1
20 | SB1 | Tactile switches | "Кнопка" | BUT: 2PADS 2x2mm | Digi-Key | CW103-ND | GRB112B802BR1 | CW Industries | 1 | 1 | 24638 | 4.25 | 4.25
21 | U1 | IC REG LINEAR 3.3V 600MA SOT25 | AP2112K-3.3TRG1 | SOT-25 | Digi-Key | AP2112K-3.3TRG1DICT-ND | AP2112K-3.3TRG1 | Diodes | 1 | 1 | 47145 | 0.37 | 0.37
22 | VD1 |  |  | CH0603LR | Digi-Key | 160-1447-1-ND | LTST-C191KRKT | Vishay Lite-On | 1 | 1 | 1135146 | 0.26 | 0.26
23 | VD2 |  | BAT54XV2T1G | SOD523 | Digi-Key | BAT54XV2T1GOSCT-ND | BAT54XV2T1G | ON Semiconductor | 1 | 1 | 4375698 | 0.26 | 0.26
24 | WA1 | 1.583GHz GPS Ceramic Patch RF Antenna 1.559GHz ~ 1.610GHz 17dBi - - | AEACAQ190012-S915 |  | Digi-Key | 535-14498-ND | AEACAQ190012-S915 | Abracon | 1 | 1 | 2510 | 5.95 | 5.95
25 | WA2 | 1.583GHz GPS Ceramic Patch RF Antenna 1.559GHz ~ 1.610GHz 17dBi - - | 2111400100 |  | Digi-Key | WM25681-ND | 2111400100 | Molex | 1 | 1 | 18788 | 2.66 | 2.66
26 | X1 |  | PH2-14-UA | CON: PLD-14_SHIFTED | Digi-Key | 2057-PH2-14-UA-ND | PH2-14-UA | Adam Equipment | 1 | 1 | 14116 | 0.24 | 0.24
27 | X2 | USB | "microUSB" | CON: MicroUSB - TH | Digi-Key | WM1399CT-ND | 105017-0001 | Molex | 1 | 1 | 60596 | 1.01 | 1.01
28 | XW1 | RF | u.Fl | CON: u.Fl | Digi-Key | CONUFL001-SMD-TCT-ND | CONUFL001-SMD-T | Linx | 1 | 1 | 225243 | 0.71 | 0.71
29 |  | LIGHT PIPE CLEAR RIGID 5MM |  |  | Digi-Key | 492-1799-ND | PLP5-2-1250 | Bivar Inc. | 2 | 2 | 54879 | 1.23 | 2.46
30 | ZQ1 | Crystal 8MHz ±30ppm (Tol) ±30ppm (Stability) 18pF FUND 100Ohm 4-Pin SMD T/R | FY0800018 | FY0800018-Footprint-1 | Digi-Key | FY0800018DKR-ND | FY0800018 | Diodes | 1 | 1 | 69574 | 0.77 | 0.77
31 |  | Пластиковый корпус G1910 |  |  | GAINTA | G1910 - пластиковый корпус Gainta (https://www.gainta.com/g1910.html) | Цвет черный |  | 1 | 1 |  | 3 | 3
 |  |  |  |  |  |  |  |  |  |  |  |  | 70.133

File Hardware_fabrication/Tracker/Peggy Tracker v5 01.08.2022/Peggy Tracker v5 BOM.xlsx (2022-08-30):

 | Peggy Tracker.PrjPcb
 | Set: | 1
# | Designator | Description | Name | Footprint | Supplier 1 | Supplier Part Number 1 | Manufacturer Part Number 1 | Manufacturer Part Number 2 | Manufacturer 1 | Manufacturer 2 | Quantity | Total Quantity | Supplier Stock 1 | Supplier Unit Price 1 | Total Price
1 | C1 | CAP CER 10000PF 50V X7R 0603 | GCM188R71H103KA37D | CAPC1608X09N | Digi-Key | 490-4778-6-ND | GCM188R71H103KA37D |  | Murata |  | 1 | 1 | 9024384 | 0.12 | 0.12
2 | C2 | CAP CER 0.1UF 50V X7R 0603 | GCM188R71H104KA57D | CAPC1608X09N | Digi-Key | 490-4779-1-ND | GCM188R71H104KA57D |  | Murata |  | 1 | 1 | 18094667 | 0.11 | 0.11
3 | C3 | CAP CER 10UF 10V X7S 0805 | CL21Y106KPQVPNE | CAPC2013X135X45NL10T25 | Digi-Key | 1276-6685-6-ND | CL21Y106KPQVPNE |  | Samsung |  | 1 | 1 | 140486 | 0.34 | 0.34
4 | C4, C5, C7 | Cap Ceramic 10uF 16V X7R 20% SMD 1206 125°C Embossed T/R | 10uF | CH1206C | Digi-Key | 1276-6641-1-ND | CL31B106MOHNNNE |  | Samsung |  | 3 | 3 | 1207934 | 0.21 | 0.63
5 | C6, C8 | Cap Ceramic 10uF 16V X7R 20% SMD 1206 125°C Embossed T/R | 2.2uF | CH0805C | Digi-Key | 490-14467-1-ND | GRM21BR71E225KE11L |  | Murata |  | 2 | 2 | 1921319 | 0.19 | 0.38
6 | C9, C10 | 0603 50V C0G 27pF 5% multilayer ceramic capacitor | CC0603JPNPO9BN270 | CAPC1608X87X35NL15T15 | Digi-Key | 13-CC0603JPNPO9BN270DKR-ND | CC0603JPNPO9BN270 |  | Yageo |  | 2 | 2 | 6411 | 0.1 | 0.2
7 | C11, C16, C17, C18, C19, С1 | CAP CER 0.1UF 50V X7R 0603 | GCM188R71H104KA57D | CAPC1608X09N | Digi-Key | 490-4779-6-ND | GCM188R71H104KA57D |  | Murata |  | 6 | 6 | 18094667 | 0.11 | 0.66
8 | C12, C13 | CAP CER 15PF 50V C0G/NPO 0603 | 15pF | CH0603C | Digi-Key | 311-1060-1-ND | CC0603JRNPO9BN150 |  | Yageo |  | 2 | 2 | 721063 | 0.1 | 0.2
9 | C14, C15, С2 | 10 µF ±10% 16V Ceramic Capacitor X7R 1206 (3216 Metric) | GCM31CR71C106KA64K | CAPC3216X190X55NL30T25 | Digi-Key | 490-14746-6-ND | GCM31CR71C106KA64K |  | Murata |  | 3 | 3 | 62593 | 0.43 | 1.29
10 | D1 | Charge Pump Switching Regulator 3.3V | TPS60120PWPR | 20-TSSOP (PAD) | Digi-Key | 296-48756-1-ND | TPS60120PWPR |  | Texas Instruments |  | 1 | 1 | 12085 | 2.66 | 2.66
11 | D2 | RTC | MCP79402-I/SN | 8-SOIC | Digi-Key | MCP79402-I/SN-ND | MCP79402-I/SN | DS1338Z-3+T&R | Microchip | Analog Devices Inc./Maxim Integrated | 1 | 1 | 1150 | 1.05 | 1.05
12 | DD1 | IC Receiver Gps/gnss 18LCC | MAX-M8C-0 | MAXM8C0 | Digi-Key | 672-MAX-M8C-0DKR-ND | MAX-M8C-0 |  | u-blox |  | 1 | 1 | 100 | 21 | 21
13 | DD2 | RF TXRX MODULE ISM<1GHZ | RFM95W-868S2 | RFM95W-868S2 |  |  | RFM95W-868S2 |  | RF Solutions |  | 1 | 1 |  |  | 0
14 | GB1, GB2, GB3, GB4 |  | L91 |  | Digi-Key | N602-ND | L91 |  | Energizer |  | 4 | 4 | 23842 | 4.79 | 19.16
15 | GB5 |  | CR2032VP |  | Digi-Key | N189-ND | CR2032VP |  | Energizer |  | 1 | 1 | 120302 | 0.59 | 0.59
16 | HL1 | WURTH ELEKTRONIK - 150060GS75000 - LED, Green, 520 nm, 3.2 V, 30 mA, 430 mcd RoHS Compliant: Yes | 150060GS75000 | CH0603LG | Digi-Key | 732-4971-6-ND | 150060GS75000 | LTST-C191TGKT | Wurth Electronics | Lite-On Inc. | 1 | 1 | 64196 | 0.15 | 0.15
17 | L1 | FIXED IND 27NH 440MA 210MOHM SMD | LQW18AN27NJ00D | INDC1608X10M | Digi-Key | 490-1174-1-ND | LQW18AN27NJ00D |  | Murata |  | 1 | 1 | 95759 | 0.16 | 0.16
18 | L2, L3 | Ferrite Beads High Current Chip 470Ohm 25% 100MHz 1A 0.2Ohm DCR 0805 T/R | MH2029-471Y | MH2029-471Y-Footprint-1 | Digi-Key | 118-MH2029-471YDKR-ND | MH2029-471Y |  | Bourns |  | 2 | 2 | 7471 | 0.1 | 0.2
19 | MPU1 | 8-bit Microcontroller with 32 Kbytes of ISP Flash and USB Controller, 2.7 to 5.5 V, -40 to 85 degC, 44-Pin QFP, Tray | ATMEGA32U4-AU | ATMEGA32U4-MU |  |  | ATMEGA32U4-AUR |  | Microchip |  | 1 | 1 |  |  | 0
20 | R1 | RES SMD 10 OHM 5% 1/5W 0603 | SG73P1JTTD100J | RESC1608X55X25ML10T15 | Digi-Key | 2019-SG73P1JTTD100JCT-ND | SG73P1JTTD100J |  | KOA Speer |  | 1 | 1 | 36305 | 0.11 | 0.11
21 | R2 |  | 357k | CH0603R | Digi-Key | 311-357KHRCT-ND | RC0603FR-07357KL |  | Yageo |  | 1 | 1 | 43305 | 0.1 | 0.1
22 | R3 |  | 1M | CH0603R | Digi-Key | 311-1.00MHRCT-ND | RC0603FR-071ML |  | Yageo |  | 1 | 1 | 2592389 | 0.1 | 0.1
23 | R4 |  | 732k | CH0603R | Digi-Key | 311-732KHRCT-ND | RC0603FR-07732KL |  | Yageo |  | 1 | 1 | 183939 | 0.1 | 0.1
24 | R5 | Res Thick Film 0603 4.7K Ohm 1% 1/10W 100ppm/C Molded SMD SMD Paper T/R | RMCF0603FT4K70 | RESC1609X50X30NL8T20 | Digi-Key | RMCF0603FT4K70CT-ND | RMCF0603FT4K70 |  | Stackpole Electronics |  | 1 | 1 | 9250111 | 0.1 | 0.1
25 | R6 |  | 47k | CH0603R | Digi-Key | 311-47.0KHRCT-ND | RC0603FR-0747KL |  | Yageo |  | 1 | 1 | 12049890 | 0.1 | 0.1
26 | R7 | Chip Resistor, 100 KOhm, +/- 1%, 0.1 W, -55 to 155 degC, 0603 (1608 Metric) | Resistor 100k +/-1% 0603 100 mW | RESC1608X55X25NL10T15 | Digi-Key | 311-100KHRCT-ND | RC0603FR-07100KL |  | Yageo |  | 1 | 1 | 15475549 | 0.1 | 0.1
27 | R8 |  | 523k | CH0603R | Digi-Key | 311-523KHRCT-ND | RC0603FR-07523KL |  | Yageo |  | 1 | 1 | 108398 | 0.1 | 0.1
28 | R9 | 510 Ohms ±5% 0.1W, 1/10W Chip Resistor 0603 (1608 Metric) Automotive AEC-Q200 Thick Film | RMCF0603JT510R | RESC1608X55X25NL10T15 | Digi-Key | RMCF0603JT510RCT-ND | RMCF0603JT510R |  | Stackpole Electronics |  | 1 | 1 | 5940 | 0.1 | 0.1
29 | VD1 |  | DESD3V3S1BL-7B | X1-DFN1006-2 (0402 ) | Digi-Key | DESD3V3S1BL-7BDICT-ND | DESD3V3S1BL-7B |  | Diodes |  | 1 | 1 | 2077483 | 0.33 | 0.33
30 | WA1 |  |  | CH0201L | Digi-Key | 1477-CRJKS0010-LNA-G65U-ND | CRJKS0010-LNA-G65U |  | NimbeLink |  | 1 | 1 | 2100 | 11 | 11
31 | WA2 |  | 1.575GHZ | CH0201L | Digi-Key | MIKE3A/3M/SMAM/S/S/17-ND | MIKE3A/3M/SMAM/S/S/17 |  | Siretta |  | 1 | 1 | 984 | 17.85 | 17.85
32 | X1 | Battery Holder (Open) AA 4 Cell PC Pin | BK-1279-PC8 | CON: 0533750810 | Digi-Key | BK-1279-PC8-ND | BK-1279-PC8 |  | Memory Protection Devices |  | 1 | 1 | 2116 | 6.13 | 6.13
33 | X2 |  | BA2032SM | CON: BA2032SM | Digi-Key | BA2032-ND | BA2032 |  | Memory Protection Devices |  | 1 | 1 | 128657 | 1.78 | 1.78
34 | X3 | CONN PLUG HOUSING EP .156 2POS | 1-1123722-2 | CON: 1-1123723-2 | Digi-Key | A30501-ND | 1-1123722-2 |  | TE Connectivity |  | 1 | 1 | 23964 | 0.19 | 0.19
35 | X4 | CONN HEADER VERT 2POS 3.96MM | 1-1123723-2 | CON: 1-1123723-2 | Digi-Key | A111830-ND | 1-1123723-2 |  | TE Connectivity |  | 1 | 1 | 253873 | 0.27 | 0.27
36 | X5 | Conn Unshrouded Header HDR 14 POS 2.54mm Solder ST Top Entry SMD Tube | TSM-107-01-T-DV | SMTC-TSM-107-01-X-DV | Digi-Key | SAM10810-ND | TSM-107-01-T-DV |  | Samtec |  | 1 | 1 | 7278 | 1.76 | 1.76
37 | X6 | RF | SMA | CON: SMA | Digi-Key | WM5543-ND | 73391-0060 |  | Molex |  | 1 | 1 | 35214 | 3.88 | 3.88
38 | XW1, XW3 | RF Connectors / Coaxial Connectors SMA ST PCB-JCK STD EMT | 732512120 | New footprint 1 | Digi-Key | WM5536-ND | 73251-2120 |  | Molex |  | 2 | 2 | 9271 | 4.49 | 8.98
39 | XW2 | CONN UMC JACK STR SMD | CONUFL001-SMD-T | u.Fl | Digi-Key | CONUFL001-SMD-TDKR-ND | CONUFL001-SMD-T |  | Linx |  | 1 | 1 | 170376 | 0.71 | 0.71
40 | ZQ1 | Crystal 8MHz ±30ppm (Tol) ±30ppm (Stability) 18pF FUND 100Ohm 4-Pin SMD T/R | FY0800018 | FY0800018-Footprint-1 | Digi-Key | FY0800018DKR-ND | FY0800018 |  | Diodes |  | 1 | 1 | 64899 | 0.8 | 0.8
41 | ZQ2 |  | 32.7680KHZ | OSC: 3215 | Digi-Key | 535-9542-1-ND | ABS07-32.768KHZ-T |  | Abracon |  | 1 | 1 | 1403146 | 0.72 | 0.72
 |  |  |  |  |  |  |  |  |  |  |  |  |  |  | 104.21

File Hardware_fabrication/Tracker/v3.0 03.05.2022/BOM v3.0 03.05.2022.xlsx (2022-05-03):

Line # | Description | Designator | Manufacturer | Manufacturer Part Number
 | CAP CER 10000PF 50V X7R 0603 | C1 | Murata | GCM188R71H103KA37D
 | CAP CER 0.1UF 50V X7R 0603 | C2, C4, C6, C7, C8 | Murata | GCM188R71H104KA57D
 | CAP CER 10UF 10V X7S 0805 | C3, C5 | Samsung | CL21Y106KPQVPNE
 | 700-mA, High-Efficiency MicroSiP Step-Down Converter (PROFILE <1mm) 8-uSiP -40 to 85 | DA1 | Texas Instruments | TPS82698SIPR
 | IC Receiver Gps/gnss 18LCC | DD1 | u-blox | MAX-M8C-0
 | RAK3172 WisDuo LPWAN Module | DD2 | RAK Wireless | RAK3172(H)
 | FIXED IND 27NH 440MA 210MOHM SMD | L1 | Murata | LQW18AN27NJ00D
 | RES SMD 10 OHM 5% 1/5W 0603 | R1 | KOA Speer | SG73P1JTTD100J
 | RES SMD 10K OHM 1% 1/10W 0603 | R2 | Stackpole Electronics Inc | RMCF0603FT10K0
 | RES 100K OHM 1% 1/10W 0603 | R3 | Stackpole Electronics Inc | RMCF0603FT100K
 | RES SMD 237K OHM 1% 1/10W 0603 | R6 | Panasonic | ERJ-3EKF2373V
 | Black 24 AWG Jumper Lead Socket to Socket Tin 12.0 | TP1, TP2 | JST Sales America Inc. | ASPHSPH24K305
 | Battery Holder Coin 20MM SMD | X1 | Memory Protection Devices | BA2032SM
 | CONN HEADER VERT 2POS 2MM | X3 | Japan Solderless Terminals | JST B2B-PH-K-S(LF)(SN)
 | CONN HOUSING PH 2POS 2MM WHITE | X4 | JST | PHR-2
 | Conn Unshrouded Header HDR 5 POS 2.54mm Solder ST Thru-Hole Carton | XP2 | TE Connectivity | 5-146278-8
 | CONN UMC JACK STR SMD | XW1, XW2 | Linx Technologies Inc. | CONUFL001-SMD-T

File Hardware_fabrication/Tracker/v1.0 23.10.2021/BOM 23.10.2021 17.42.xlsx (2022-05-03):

Line # | Name | Description | Designator | Quantity | Supplier 1 | Supplier Unit Price 1 | Supplier Subtotal 1 | Supplier Stock 1 | ComponentType
 | GCM188R71H103KA37D | CAP CER 10000PF 50V X7R 0603 | C1 | 1 | Digi-Key | 0.12 | 0.12 | 9059897 | Capacitors
 | C0603C104K5RAC7411 | Cap Ceramic 0.1uF 50V X7R 10% SMD 0603 125°C Paper T/R | C2, C4, C6 | 3 | Digi-Key | 0.0161 | 241.5 | 2970000 | Capacitors
 | C0603C106M8PAC7867 | Cap Ceramic 10uF 10V X5R 20% SMD 0603 85°C Paper T/R | C3, C5 | 2 | Digi-Key | 0.48 | 0.96 | 39725 | Capacitors
 | LMK316AB7106MLHT | Cap Ceramic 10uF 10V X7R 20% Ultra Low ESR Pad SMD 1206 125C Automotive T/R | C7 | 1 | Digi-Key | 0.37 | 0.37 | 6975 | Capacitors
 | CL21A226MAQNNNE | SAMSUNG ELECTRO-MECHANICS - CL21A226MAQNNNE - SMD Multilayer Ceramic Capacitor, 22 µF, 25 V, 0805 [2012 Metric], ± 20%, X5R, CL Series | C8 | 1 | Mouser | 0.33 | 0.33 | 4395 | Capacitors
 | TPS63000IDRCRQ1 | IC REG BUCK BOOST ADJ 1.6A 10SON | DA1 | 1 | LCSC | 16.91 | 16.91 | 95 | Power Supply
 | MAX-M8C-0 | IC Receiver Gps/gnss 18LCC | DD1 | 1 | Digi-Key | 21 | 21 | 25791 | Wireless
 | RAK3172(H) | RAK3172 WisDuo LPWAN Module | DD2 | 1 |  |  |  |  | Radio&RF
 | LQW15AN27NG00D | INDUCTOR | L1 | 1 | Digi-Key | 0.18 | 0.18 | 257888 | Inductors
 | SRU5018-3R5Y | Ind Power Shielded Wirewound 3.5uH 30% 100KHz 9Q-Factor Ferrite 2.1A T/R | L2 | 1 | Digi-Key | 0.96 | 0.96 | 1151 | Inductors
 | ERJ-PA3J100V | RES SMD 10 OHM 5% 1/4W 0603 | R1 | 1 | Digi-Key | 0.1 | 0.1 | 17706 | Resistors
 | MCT06030C1002FP500 | Res Thin Film 0603 10K Ohm 1% 1/10W ±50ppm/°C Molded SMD SMD Paper T/R | R2 | 1 | Mouser | 0.13 | 0.13 | 1455 | Resistors
 | RMCF0603ZT0R00 | Res Thkflm 0603 0 Ohm Jumper 1/10W 100Ppm/ C Smd Rohs Compliant: Yes | R3 | 1 | Arrow Electronics | 0.0037 | 0.0037 | 2193118 | Resistors
 | RMCF0603JT1M00 | RES 1M OHM 5% 1/10W 0603 | R4 | 1 | Digi-Key | 0.1 | 0.1 | 459975 | Resistors
 | ERJ-3EKF1783V | ICK FILM, RESISTOR, 178KOHM, 100mW, ±1%; Product Range:PANASONIC - ERJ Series; Resistance:178kohm; Power Rating:100mW; Resistance Tolerance:± 1%; Resistor Case Style:0603 ^1608 Metric]; Resistor Element Type:Thick Film; MSL:- | R5 | 1 | Digi-Key | 0.1 | 0.1 | 4244 | Resistors
 | BA2032SM | Battery Holder Coin 20MM SMD | X1 | 1 |  |  |  |  | Connectors
 | ST-LINK-SWD-CONNECTOR | Conn Unshrouded Header HDR 4 POS 2.54mm Solder ST Thru-Hole Bag | X2 | 1 |  |  |  |  | Connectors
 | 1803277 | Male Header, Pitch 3.81 mm, 1 x 2 Position, Height 7.25 mm, Tail Length 3.4 mm, RoHS, Bulk | X3 | 1 | Digi-Key | 0.86 | 0.86 | 13086 | Connectors
 | 61300411121 | Conn Unshrouded Header HDR 4 POS 2.54mm Solder ST Thru-Hole Bag | XP1 | 1 |  |  |  |  | Connectors
 | CON-SMA-EDGE-S | CONN SMA JACK STR EDGE MNT | XS1, XS2 | 2 | Digi-Key | 1.69 | 3.38 | 8310 | Connectors

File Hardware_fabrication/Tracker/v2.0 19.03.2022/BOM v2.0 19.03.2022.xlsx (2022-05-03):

Line # | Designator | Manufacturer | Manufacturer Part Number | Description
 | C1 | Murata | GCM188R71H103KA37D | CAP CER 10000PF 50V X7R 0603
 | C2, C4, C6 | Murata | GCM188R71H104KA57D | CAP CER 0.1UF 50V X7R 0603
 | C3, C5, C7 | Samsung | CL21Y106KPQVPNE | CAP CER 10UF 10V X7S 0805
 | C8 | TDK | C2012X5R1C226K125AC | TDK - C2012X5R1C226K125AC - SMD Multilayer Ceramic Capacitor, 22 µF, 16 V, 0805 [2012 Metric], ± 10%, X5R, C Series
 | DA1 | Texas Instruments | TPS63000DRCR | IC REG BUCK BOOST ADJ 1.6A 10SON
 | DD1 | u-blox | MAX-M8C-0 | IC Receiver Gps/gnss 18LCC
 | DD2 | RAK Wireless | RAK3172(H) | RAK3172 WisDuo LPWAN Module
 | L1 | Murata | LQW18AN27NJ00D | FIXED IND 27NH 440MA 210MOHM SMD
 | L2 | Bourns | SRU5018-3R5Y | Ind Power Shielded Wirewound 3.5uH 30% 100KHz 9Q-Factor Ferrite 2.1A T/R
 | R1 | KOA Speer | SG73P1JTTD100J | RES SMD 10 OHM 5% 1/5W 0603
 | R2 | Stackpole Electronics Inc | RMCF0603FT10K0 | RES SMD 10K OHM 1% 1/10W 0603
 | R3 | Stackpole Electronics Inc | RMCF0603FT100K | RES 100K OHM 1% 1/10W 0603
 | R4 | Stackpole Electronics | RMCF0603JT1M00 | RES 1M OHM 5% 1/10W 0603
 | R5 | Panasonic | ERJ-3EKF1783V | ICK FILM, RESISTOR, 178KOHM, 100mW, ±1%; Product Range:PANASONIC - ERJ Series; Resistance:178kohm; Power Rating:100mW; Resistance Tolerance:± 1%; Resistor Case Style:0603 ^1608 Metric]; Resistor Element Type:Thick Film; MSL:-
 | R6 | Panasonic | ERJ-3EKF2373V | RES SMD 237K OHM 1% 1/10W 0603
 | TP1, TP2 | JST Sales America Inc. | ASPHSPH24K305 | Black 24 AWG Jumper Lead Socket to Socket Tin 12.0
 | X1 | Memory Protection Devices | BA2032SM | Battery Holder Coin 20MM SMD
 | X3 | Japan Solderless Terminals | JST B2B-PH-K-S(LF)(SN) | CONN HEADER VERT 2POS 2MM
 | X4 | JST | PHR-2 | CONN HOUSING PH 2POS 2MM WHITE
 | XP2 | TE Connectivity | 5-146278-8 | Conn Unshrouded Header HDR 5 POS 2.54mm Solder ST Thru-Hole Carton
 | XW1, XW2 | Linx Technologies Inc. | CONUFL001-SMD-T | CONN UMC JACK STR SMD

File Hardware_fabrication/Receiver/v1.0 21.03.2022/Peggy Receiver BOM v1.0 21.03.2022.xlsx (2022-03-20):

Line # | Description | Designator | Manufacturer | Manufacturer Part Number
 | CAP CER 0.1UF 50V X7R 0603 | C1 | Murata | GCM188R71H104KA57D
 | Cap Ceramic 10uF 10V X5R 20% SMD 0603 85°C Paper T/R | C2 | KEMET | C0603C106M8PAC7867
 | CAP CER 0.1UF 50V X7R 0603 | C3 | Murata | GCM188R71H104KA57D
 | TDK - C2012X5R1C226K125AC - SMD Multilayer Ceramic Capacitor, 22 µF, 16 V, 0805 [2012 Metric], ± 10%, X5R, C Series | C4 | TDK | C2012X5R1C226K125AC
 | Cap Ceramic 10uF 10V X5R 20% SMD 0603 85°C Paper T/R | C5 | KEMET | C0603C106M8PAC7867
 | IC REG BUCK BOOST ADJ 1.6A 10SON | DA1 | Texas Instruments | TPS63000DRCR
 | Bluetooth 4.0 Module | DD1 | HC-08 | HC-08
 | RAK3172 WisDuo LPWAN Module | DD2 | RAK Wireless | RAK3172(H)
 | Ind Power Shielded Wirewound 3.5uH 30% 100KHz 9Q-Factor Ferrite 2.1A T/R | L1 | Bourns | SRU5018-3R5Y
 | RES 10K OHM 0.1% 1/16W 0603 | R1
 | RES 100K OHM 1% 1/10W 0603 | R3 | Stackpole Electronics Inc | RMCF0603FT100K
 | RES SMD 237K OHM 1% 1/10W 0603 | R4 | Panasonic | ERJ-3EKF2373V
 | RES 1M OHM 5% 1/10W 0603 | R5 | Stackpole Electronics | RMCF0603JT1M00
 | ICK FILM, RESISTOR, 178KOHM, 100mW, ±1%; Product Range:PANASONIC - ERJ Series; Resistance:178kohm; Power Rating:100mW; Resistance Tolerance:± 1%; Resistor Case Style:0603 ^1608 Metric]; Resistor Element Type:Thick Film; MSL:- | R6 | Panasonic | ERJ-3EKF1783V
 | Slide Switch, SPDT, 500 V, -20 to 70 degC, 3-Pin THD, RoHS, Bulk | SW1 | E-Switch | EG1218
 | Black 24 AWG Jumper Lead Socket to Socket Tin 12.0 | TP1 | JST Sales America Inc. | ASPHSPH24K305
 | Black 24 AWG Jumper Lead Socket to Socket Tin 12.0 | TP2 | JST Sales America Inc. | ASPHSPH24K305
 | CONN SMA JACK STR EDGE MNT | X1 | RF Solutions | CON-SMA-EDGE-S
 | Micro USB 2.0 B Receptacle, 5 Position, Height 3.24 mm, -55 to 85 degC, RoHS, Tape and Reel | X2 | Amphenol ICC (FCI) | 10103594-0001LF
 | CONN HEADER VERT 2POS 2MM | X3-1 | Japan Solderless Terminals | JST B2B-PH-K-S(LF)(SN)
 | CONN HOUSING PH 2POS 2MM WHITE | X3-2 | JST | PHR-2

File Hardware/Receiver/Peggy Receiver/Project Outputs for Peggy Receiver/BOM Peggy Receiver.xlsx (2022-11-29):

 | Peggy Receiver.PrjPcb
 | Set: | 1
# | Designator | Description | Name | Footprint | Supplier 1 | Supplier Part Number 1 | Manufacturer Part Number 1 | Manufacturer 1 | Quantity | Total Quantity | Supplier Stock 1 | Supplier Unit Price 1 | Total Price
1 | C1, C8, C9, C10, C11 |  | 0.1uF | CH0603C | Digi-Key | 490-4779-1-ND | GCM188R71H104KA57D | Murata | 5 | 5 | 17232935 | 0.11 | 0.55
2 | C2, C3 | 0603 50V C0G 27pF 5% multilayer ceramic capacitor | CC0603JPNPO9BN270 | CAPC1608X87X35NL15T15 | Digi-Key | 13-CC0603JPNPO9BN270DKR-ND | CC0603JPNPO9BN270 | Yageo | 2 | 2 | 20149 | 0.1 | 0.2
3 | C4, C5, C6, C7, C12, C13, C14 | CAP CER 10UF 16V X7R 1206 | 10uF | CH1206C | Digi-Key | 490-14746-1-ND | GCM31CR71C106KA64K | Murata | 7 | 7 | 9833 | 0.41 | 2.87
4 | C15 |  | 1uF | CH0603C | Digi-Key | 1276-1946-1-ND | CL10B105KP8NNNC | Samsung | 1 | 1 | 10639857 | 0.1 | 0.1
5 | D1 | Bluetooth 4.0 module | HC-08 | MOD: SH-HC-08 |  | https://aliexpress.ru/item/32817019978.html?sub=1010658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 | ЦветHC-08 with Board |  | 1 | 1 |  |  | 0
6 | D2 | Li-ion chargers | MCP73831T-2ATI/OT | SOT23-5 | Digi-Key | MCP73831T-2ATI/OTCT-ND | MCP73831T-2ATI/OT | Microchip | 1 | 1 | 42968 | 0.76 | 0.76
7 | DD1 | RF TXRX MODULE ISM<1GHZ | RFM95W-868S2 | RFM95W-868S2 |  | https://aliexpress.ru/item/32810607598.html?sku_id=65554951845 | RFM95W-868S2 | RF Solutions | 1 | 1 |  |  | 0
8 | GB1 | LiPo Battery | LP103450JH+PCM+PTC+2 WIRES 70MM | BAT: 34.5X52MM | Digi-Key | 1908-LP103450JH+PCM+PTC+2WIRES70MM-ND | LP103450JH+PCM+PTC+2WIRES70MM | Jauch | 1 | 1 | 2306 | 17.33 | 17.33
9 | HL1 | WURTH ELEKTRONIK - 150060GS75000 - LED, Green, 520 nm, 3.2 V, 30 mA, 430 mcd RoHS Compliant: Yes | 150060GS75000 | CH0603LG | Mouser | 710-150060GS75000 | 150060GS75000 | Wurth Electronics | 1 | 1 | 185610 | 0.15 | 0.15
10 | L1, L2, L3 | Ferrite Beads High Current Chip 470Ohm 25% 100MHz 1A 0.2Ohm DCR 0805 T/R | MH2029-471Y | MH2029-471Y-Footprint-1 | Digi-Key | 118-MH2029-471YDKR-ND | MH2029-471Y | Bourns | 3 | 3 | 14551 | 0.1 | 0.3
11 | MPU1 | 8-bit Microcontroller with 32 Kbytes of ISP Flash and USB Controller, 2.7 to 5.5 V, -40 to 85 degC, 44-Pin QFP, Tray | ATMEGA32U4-AU | ATMEGA32U4-MU | Verical | ATMEGA32U4-AU | ATMEGA32U4-AU | Microchip / Atmel | 1 | 1 | 320 | 3.49 | 3.49
12 | R1 | Res Thick Film 0603 4.7K Ohm 1% 1/10W 100ppm/C Molded SMD SMD Paper T/R | RMCF0603FT4K70 | CH0603R | NAC Semi | RMCF0603FT4K70 | RMCF0603FT4K70 | Stackpole Electronics | 1 | 1 | 9650000 | 0.005 | 0.005
13 | R2, R8, R9 |  | 1k | CH0603R | Digi-Key | 311-1.00KHRCT-ND | RC0603FR-071KL | Yageo | 3 | 3 | 30179050 | 0.021 | 0.063
14 | R3 | Chip Resistor, 100 KOhm, +/- 1%, 0.1 W, -55 to 155 degC, 0603 (1608 Metric) | Resistor 100k +/-1% 0603 100 mW | RESC1608X55X25NL10T15 | Newark | 75X0140 | RC0603FR-07100KL | Yageo | 1 | 1 | 170000 | 0.003 | 0.003
15 | R4 | RES 3.6K OHM 1% 1/10W 0603 | 3.6K | CH0603R | Digi-Key | 311-3.60KHRCT-ND | RC0603FR-073K6L | Yageo | 1 | 1 | 579825 | 0.1 | 0.1
16 | R5, R7 | RES 22 OHM 1% 1/10W 0603 | 22 | CH0603R | Digi-Key | 311-22.0HRCT-ND | RC0603FR-0722RL | Yageo | 2 | 2 | 4954137 | 0.1 | 0.2
17 | R6 | 510 Ohms ±5% 0.1W, 1/10W Chip Resistor 0603 (1608 Metric) Automotive AEC-Q200 Thick Film | RMCF0603JT510R | RESC1608X55X25NL10T15 | Digi-Key | RMCF0603JT510RCT-ND | RMCF0603JT510R | Stackpole Electronics | 1 | 1 | 174797 | 0.1 | 0.1
18 | SB1 | Tactile switches | "Кнопка" | BUT: 2PADS 2x2mm | Digi-Key | CW103-ND | GRB112B802BR1 | CW Industries | 1 | 1 | 24711 | 4.25 | 4.25
19 | U1 | IC REG LINEAR 3.3V 600MA SOT25 | AP2112K-3.3TRG1 | SOT-25 | Digi-Key | AP2112K-3.3TRG1DICT-ND | AP2112K-3.3TRG1 | Diodes | 1 | 1 | 63438 | 0.37 | 0.37
20 | VD1 |  |  | CH0603LR | Digi-Key | 160-1447-1-ND | LTST-C191KRKT | Vishay Lite-On | 1 | 1 | 1112460 | 0.26 | 0.26
21 | VD2 |  | BAT54XV2T1G | SOD523 | Digi-Key | BAT54XV2T1GOSCT-ND | BAT54XV2T1G | ON Semiconductor | 1 | 1 | 4396727 | 0.26 | 0.26
22 | WA1 | 1.583GHz GPS Ceramic Patch RF Antenna 1.559GHz ~ 1.610GHz 17dBi - - | AEACAQ190012-S915 |  | Digi-Key | 535-14498-ND | AEACAQ190012-S915 | Abracon | 1 | 1 | 2511 | 5.95 | 5.95
23 | WA2 | 1.583GHz GPS Ceramic Patch RF Antenna 1.559GHz ~ 1.610GHz 17dBi - - | 2111400100 |  | Digi-Key | WM25681-ND | 2111400100 | Molex | 1 | 1 | 18923 | 2.66 | 2.66
24 | X1 |  | TSM-107-01-T-DV | CON: TSM-107-01-T-DV | Digi-Key | SAM10810-ND | TSM-107-01-T-DV | Samtec | 1 | 1 | 6943 | 1.69 | 1.69
25 | X2 | USB | "microUSB" | CON: MicroUSB - TH | Digi-Key | WM1399CT-ND | 105017-0001 | Molex | 1 | 1 | 50445 | 1.01 | 1.01
26 | XW1 | RF | u.Fl | CON: u.Fl | Digi-Key | CONUFL001-SMD-TCT-ND | CONUFL001-SMD-T | Linx | 1 | 1 | 168195 | 0.71 | 0.71
27 | ZQ1 | Crystal 8MHz ±30ppm (Tol) ±30ppm (Stability) 18pF FUND 100Ohm 4-Pin SMD T/R | FY0800018 | FY0800018-Footprint-1 | Digi-Key | FY0800018DKR-ND | FY0800018 | Diodes | 1 | 1 | 69574 | 0.77 | 0.77
 |  |  |  |  |  |  |  |  |  |  |  |  | 44.151

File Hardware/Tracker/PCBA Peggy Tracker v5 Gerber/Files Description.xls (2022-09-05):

PCBA Peggy Tracker v5 Gerber
# | Filename | Description
1 | PCBA Peggy Tracker v5 Gerber.cam | Altium Designer CAM file
2 | PCBA Peggy Tracker v5 Gerber.GBL | Bottom Signal Layer
3 | PCBA Peggy Tracker v5 Gerber.GBO | Bottom Overlay
4 | PCBA Peggy Tracker v5 Gerber.GBP | Bottom Paste
5 | PCBA Peggy Tracker v5 Gerber.GBS | Bottom Solder
6 | PCBA Peggy Tracker v5 Gerber.GKO | Keep-Out Layer
7 | PCBA Peggy Tracker v5 Gerber.GTL | Top Signal Layer
8 | PCBA Peggy Tracker v5 Gerber.GTO | Top Overlay
9 | PCBA Peggy Tracker v5 Gerber.GTP | Top Paste
10 | PCBA Peggy Tracker v5 Gerber.GTS | Top Solder
11 | PCBA Peggy Tracker v5 Gerber.TXT | Drill

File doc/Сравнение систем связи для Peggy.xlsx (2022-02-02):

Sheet: Сравнение
Сравнение систем беспроводной связи для GPS трекера Peggy
Наименование | Энергопотребление | Дальность |  |  | Пропускная способность | Тип сети | Модуляция | Кол-во точек | Частота
LoraWAN | Low | 10 км |  |  |  | star |  |  | 868 MHz
GSM | High |  |  |  |  | star
ZigBee | Low |  |  |  |  | mesh
NB-IoT | High |  |  |  |  | star
SigFox | High |  |  |  |  | star
Weightless-N
 |  | Потребление
Спутниковые системы | Модуль | Idle | Приём | Передача | Стоимость за модуль | Абонентская плата | Ссылка
Swarm |  | 3.3V@22uA сон | 3.3V@35мА | 3.3V@1A | $119 | $5/месяц. Туда входит 750 пакетов, до 192 байт в пакете | https://swarm.space/our-story/ | Над нами летает по 2-3 спутника. Можно отследить по ссылке: https://swarm.space/tracking/. Бывает, что часами не летают над точкой. Можно тут график посмотреть: https://kube.tools.swarm.space/pass-checker/
Iridium | Iridium Core 9523 | 3.2V@70mA | 3.2V@110mA | 3.2V@300mA
 | Iridium 9602 | 5V@35mA | 5V@40mA | 5V@140mA
 | Iridium 9603 | 5V@34mA | 5V@39mA | 5V@140mA |  |  | https://www.iridium.com/where-to-buy/?pid=14933
Всего 30 лошадей.
Ставят на Айгыра

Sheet: Статьи для прочтения
п/п | Польза | Название | Ссылка
1 |  | LoRa, «Стриж» и ZigBee vs NB-IoT для АСУНО. NB-IoT — основа «умного» города и «умного» света | https://led-e.ru/sys/osnova-umnogo-goroda/?utm_source=wireless&utm_medium=article
2 |  | Приемопередатчик LR1110 для LoRa с функцией геолокации компании Semtech | https://wireless-e.ru/transivery/lr1110/
3 |  | Сравнение LoRaWAN, SNBWAN и других технологий для «Интернета вещей» | https://wireless-e.ru/standarty/snbwan/
4 |  | Технология передачи данных LoRaWAN для IIoT-решений: мифы и реальность | https://wireless-e.ru/iot/tehnologiya-peredachi-dannyh/
5 |  | Модуль SIM868: функционал и практические аспекты использования | https://wireless-e.ru/radiomoduli/sim868/?link=1
6 | 1 | Новые беспроводные LTE- и NB-IoT-модули Neoway | https://wireless-e.ru/gsm/lte/n75/
7 |  | Sigfox Technical Overview | https://www.avnet.com/wps/wcm/connect/onesite/03aebfe2-98f7-4c28-be5f-90638c898009/sigfox-technical-overview.pdf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
8 |  | Краткий путеводитель по беспроводным технологиям «Интернета вещей». Часть 1. Сети, шлюзы, облака и протоколы | https://controleng.ru/besprovodny-e-tehnologii/putivoditel-iot-1/
9 |  | GLOBALSTAR SATELLITE TECHNOLOGY | https://www.globalstar.com/en-us/products/commercial-iot
10 |  | Новинки компании Semtech для технологии LoRa | https://wireless-e.ru/lorawan/novinki-dlya-tehnologii-lora/
11 |  | LG77L — новый компактный мультиформатный GNSS-модуль с ультранизким потреблением от компании Quectel | https://wireless-e.ru/gps/lg77l/
12 |  | Обзор GPS/ГЛОНАСС-модулей | https://wireless-e.ru/gps/obzor-gps-glonass-modulej/
13 |  | Исследование отечественных GPS/ГЛОНАСС-приемников | https://wireless-e.ru/gps/issledovanie-otechestvennyh-gps/
14
15
16
17
18
19
20

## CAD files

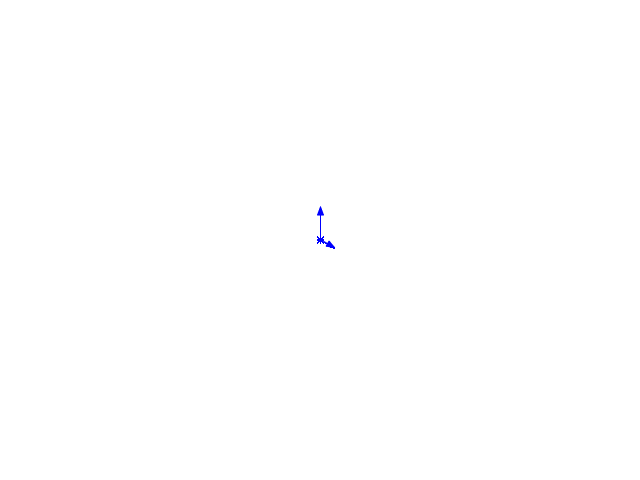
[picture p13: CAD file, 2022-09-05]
Enclosure/Tracker/Старая версия/C10.step.SLDASM
Open_CASCADE_STEP_translator_6.8_127.1.1.step
Open_CASCADE_STEP_translator_6.8_127.1.2.step
Open_CASCADE_STEP_translator_6.8_127.2.1.step

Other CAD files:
Enclosure/Tracker/Старая версия/C6.step.SLDASM
Enclosure/Tracker/Старая версия/Mid_Body-3.step.SLDASM
Enclosure/Tracker/Старая версия/R3.step.SLDASM
Enclosure/Tracker/Старая версия/PLD-14.step.SLDASM
Enclosure/Tracker/Старая версия/Designator2.step.SLDASM
Enclosure/Tracker/Старая версия/C11.step.SLDASM
Enclosure/Tracker/Старая версия/C13.step.SLDASM
Enclosure/Tracker/Старая версия/HL1.step.SLDASM
Enclosure/Tracker/Старая версия/C3.step.SLDASM
Enclosure/Tracker/Старая версия/Mid_Body-1.step.SLDASM
Enclosure/Tracker/Старая версия/X1.step.SLDASM
Enclosure/Tracker/Старая версия/User_Library-RFM96W.step.SLDASM
Enclosure/Tracker/Старая версия/3.step.SLDASM
Enclosure/Tracker/Старая версия/Designator4.step.SLDASM
Enclosure/Tracker/Старая версия/R2.step.SLDASM
Enclosure/Tracker/Старая версия/Designator18.step.SLDASM
Enclosure/Tracker/Старая версия/Designator10.step.SLDASM
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

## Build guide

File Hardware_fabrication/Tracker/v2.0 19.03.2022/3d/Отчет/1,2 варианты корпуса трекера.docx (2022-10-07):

По проекту «Tracker Peggy» необходимо было разработать корпус трекера, который предназначен для отслеживания местоположения лошадей.

Была создана версия для печатной платы трекера, в корпусе планировалось применение плоского литиевого аккумулятора.

Корпус представлен в виде, прямоугольной формы с фасками по центру что, визуально уменьшал вид самого корпуса, также фасадная сторона крышки имела выступы с геометрическими симметричными формами. Габариты корпуса были точно смоделированы под техническое задание, и имели значения (ШхВхГ): 96х58х31 мм. Состоял из двух частей, крепежными элементами выступали болты М4 х4 шт. с тыльной стороны. Печатаная плата ложилась на выступы (бобышки) высотой 5 мм. и крепилась с помощью болтиков М3 х4 шт., тогда как аккумулятор крепился на вторую часть корпуса с помощью хомутика.

Также был разработан второй вариант корпуса трекера. Корпус представляет собой полностью прямоугольную форму с скруглениями с каждой из сторон, что позволяет при эксплуатации не травмировать животного и/или человека, плюс ко всему придает эстетичный обтекаемый вид. Габариты примерно такие же (ШхВхГ): 100х58х31 мм. В данном случае изменен был только внешний вид, так как планировалось спрятать корпус в кармашек в ошейнике, дабы избежать каких-либо внешних воздействий от животного и помогло бы немного уменьшить воздействие окружающей среды, такие как влага и смена температуры.

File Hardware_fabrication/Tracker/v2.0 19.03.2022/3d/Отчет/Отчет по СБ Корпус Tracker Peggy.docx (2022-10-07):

Цель задания

По техническим требованиям и заданию необходимо было разработать корпус трекера, который предназначен для отслеживания местоположения лошадей и других животных с целью предотвращения хищения и потери скота. Предполагается применение устройства в условиях отсутствия общедоступных беспроводных сетей связи таких как GSM и Wi-Fi.

Технические требования к корпусу изделия Peggy Tracker

Изделие состоит из следующих частей:

- ошейник с креплением для корпуса;

- корпус;

- аккумуляторная батарея;

- печатная плата.

Конструктивные требования к корпусу с ошейником

Общие требования к внешнему виду устройства: устройство небольших размеров с компактным дизайном корпуса, корпус должен быть обтекаемым, без заостренных углов, так как по условиям ТЗ будет плотно прилегать к телу животного (лошади), за счет чего устройство держит оптимальную температуры для работы, также корпус должен быть удобным в исполнений и использовании.

При этом должны учитываться следующие требования:

- максимальные габаритные размеры (ШхДхГ): 100х100х25 мм.;

- исполнение моноблочное с возможностью открытия (для смены батареи) с креплением на ошейник;

- эргономика: наглядность и понятность функциональных частей, удобство использования устройства;

- цветофактурное решение: гладкая поверхность, темные тона;

- требуется прочный пластик, пример ABS;

- вес не более 1,5 кг;

- ширина ошейника не более 100 мм.;

- устройство должно быть защищено от пыли и влаги по стандарту IP68;

- в течение периода его эксплуатации не должно быть коррозионных повреждений, приводящих к снижению тактико-технических характеристик;

- устройство должно быть устойчиво к ударам и тряске.

Разработка корпуса устройства

В программе SolidWorks2020 был спроектирован корпус устройства. Были смоделированы все необходимые 3д модели для сборки корпуса.

В разработанном корпусе имеются отверстия для разъемов/антенны. В корпусе предусмотрены крепления для платы и для соединения между собой верхней и нижних частей корпуса.

Сборка корпуса состоит из нескольких частей, такие как: 1) основной корпус с 2) крышкой, которые крепятся между собой болтами М3 всего 4 отверстия, 3) металлического крепления, которое служит креплением между ошейником и самим корпусом за счет болтов М3 и М5, 4) печатной платой с батарейным отсеком и 5) ошейником.

Толщина корпуса S=2 мм., материал необходимый для печати корпуса на 3д принтере ABS пластик, который может выдержать температурные изменения. Свойства АБС пластика: теплостойкость 100-105 градусов, выдерживает низкие температуры до -40 градусов, дает блестящую поверхность, имеет хорошую химическую стойкость, стоек к щелочам и смазочным маслам, характеризуется пониженными электроизоляционными свойствами, нестоек к УФ-излучению.

Металлическое крепление необходимо использовать оцинкованную сталь, толщина металла S=1,5 мм., гиб 30 градусов.

Для ошейника лошади необходим материал на подобие брезентовой ткани (состав натуральный лен, хлопок и джут), либо замена этой ткани может служить парусина, так как материал будет удобен для носки животным, будет крепким и износостойким.

Все виды 3д сборки и моделей проекта показаны ниже на рисунках с 1 по 10. Также по проекту прикладываю приложение с чертежами.

Ссылки:

1. CRJKS0010-LNA-G65U NimbeLink, LLC | RF/IF and RFID | DigiKey (https://www.digikey.com/en/products/detail/nimbelink-llc/CRJKS0010-LNA-G65U/15519589) антенна;
2. MIKE3A/3M/SMAM/S/S/17 Siretta Ltd | RF/IF and RFID | DigiKey (https://www.digikey.com/en/products/detail/siretta-ltd/MIKE3A-3M-SMAM-S-S-17/6096367) антенна;
3. Welgevonden Management Newsletter Issue 2 - 2021 - Clifftop Exclusive Safari Hideaway (clifftoplodge.co.za) (https://clifftoplodge.co.za/welgevonden-management-newsletter-issue-2-2021/); Animal tracking gps hi-res stock photography and images - Alamy (https://www.alamy.com/stock-photo/animal-tracking-gps.html) примеры реализации трекера с ошейником;
4. GPS Трекер TKStar TK-905 для Лошадей, Зарядка до 60 дней, GPS слежение (126536921) купить в Алматы за 24990 тг (sicom.com.kz) (https://sicom.com.kz/p/126536921-gps-treker-tkstar-tk-905-dlya-loshadey-zaryadka-do-60-dney-gps-slezhenie/) пример корпуса трекера;
5. Свойства, различия и области применения PLA и ABS пластика « 3D « База знаний МногоЧернил.ру (mnogochernil.ru) (https://mnogochernil.ru/newsroom/abs-pla-plastic/) информация про ABS пластик.

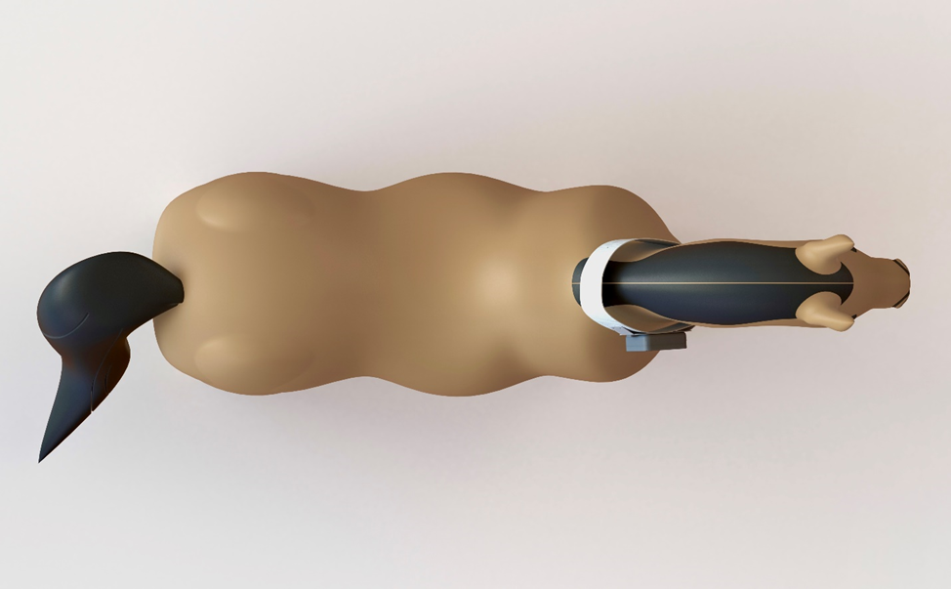
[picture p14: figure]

Рис. 1 – Вид сверху.

Показана лошадь с ошейником и корпусом трекера

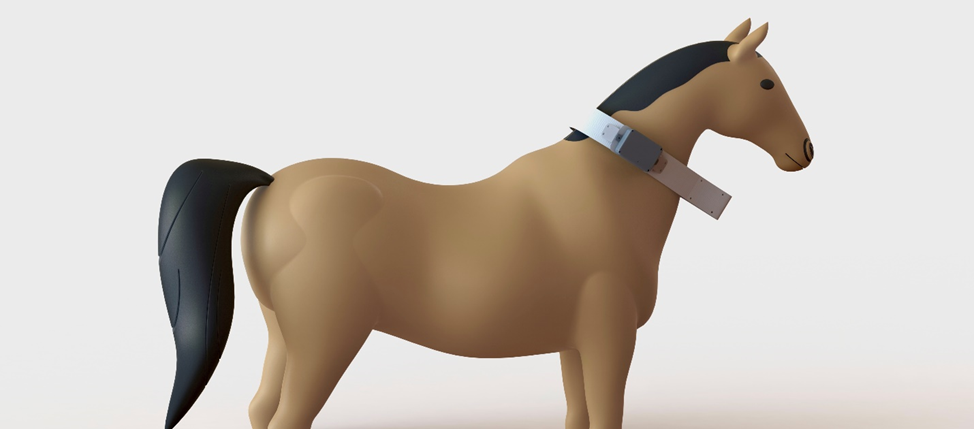
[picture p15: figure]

Рис. 2 – Фронтальный вид.

Показана лошадь с ошейником и корпусом трекера

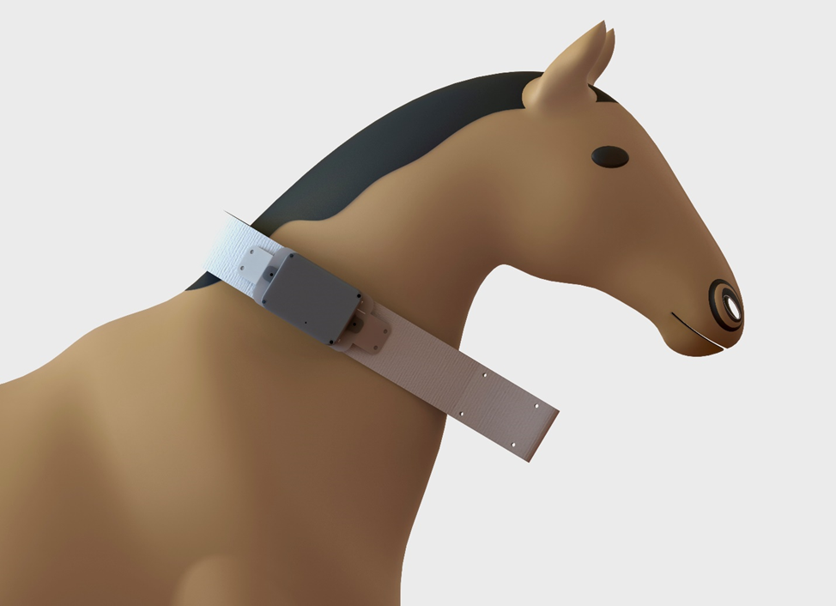
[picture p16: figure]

Рис. 3 – Профильный вид.

Показана лошадь с ошейником и корпусом трекера

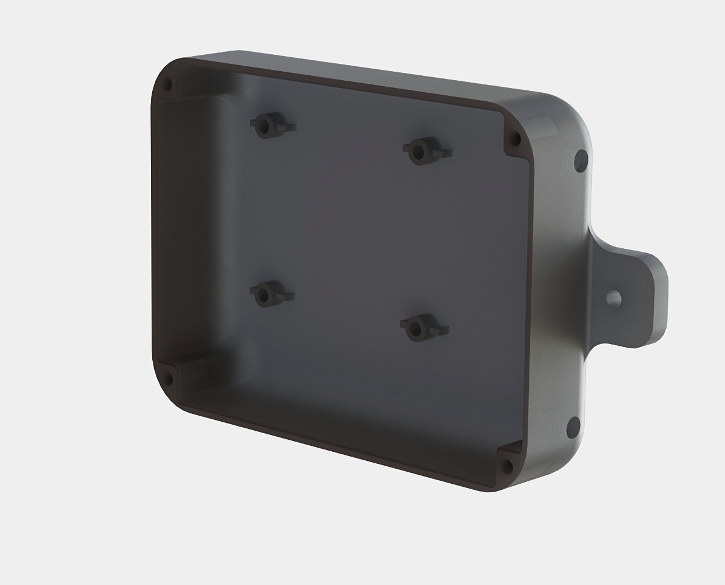
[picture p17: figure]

Рис. 4 – Вид в изометрии основой части корпуса.

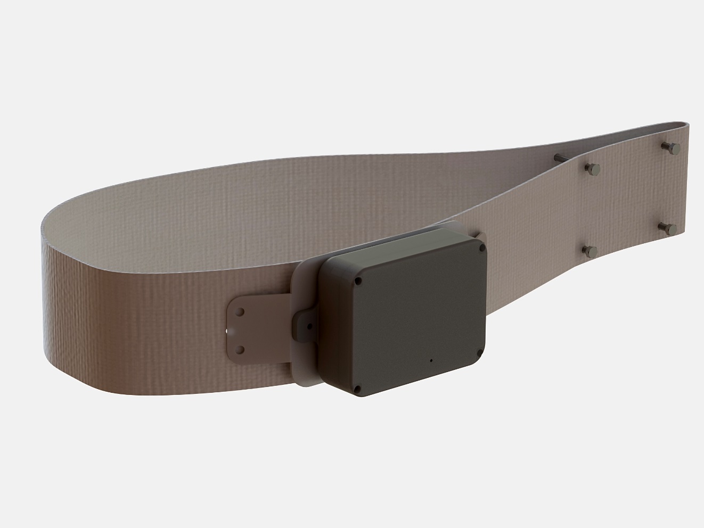
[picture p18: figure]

Рис. 5 – Изометрия сборки корпуса с предполагаемым ошейником.

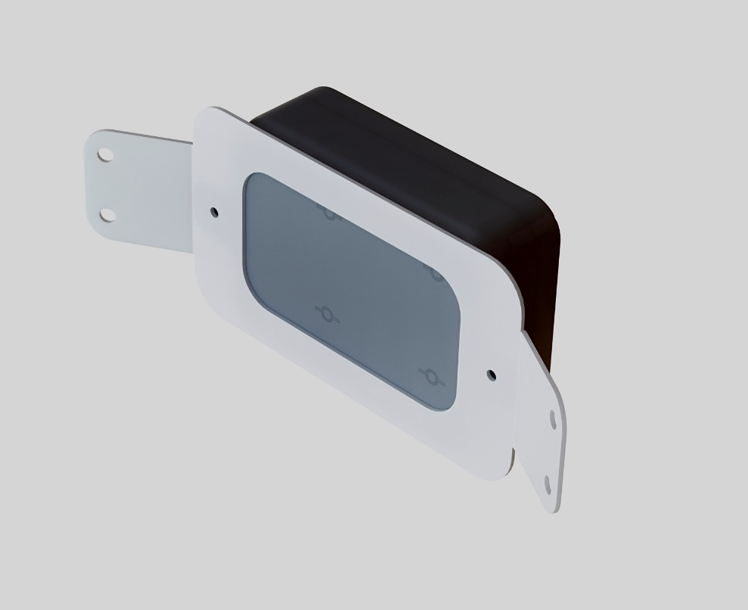
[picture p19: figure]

Рис. 6 – Вид сзади корпуса с металлическим креплением.

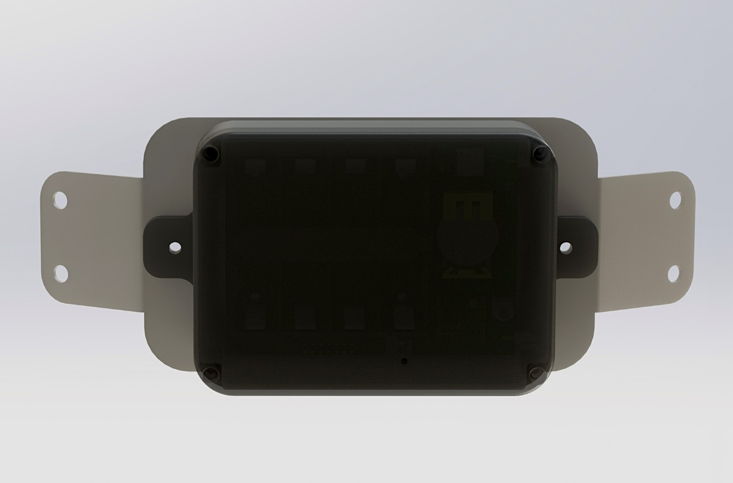
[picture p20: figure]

Рис. 7 – Фронтальный вид корпуса с металлическим креплением.

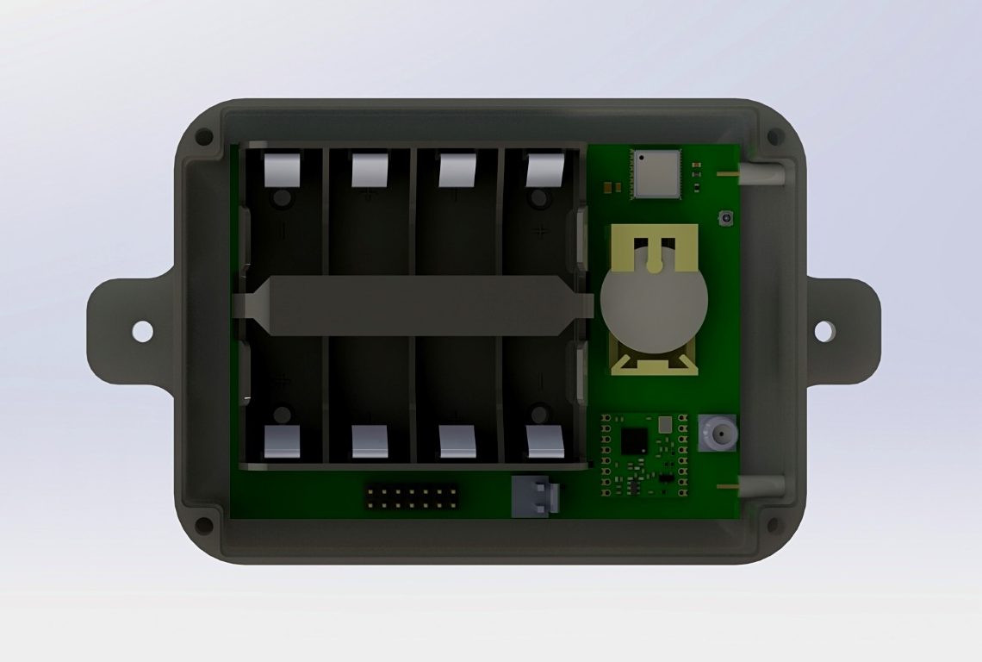
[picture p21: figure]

Рис. 8 – Вид спереди.

Расположение платы с батарейным отсеком внутри корпуса.

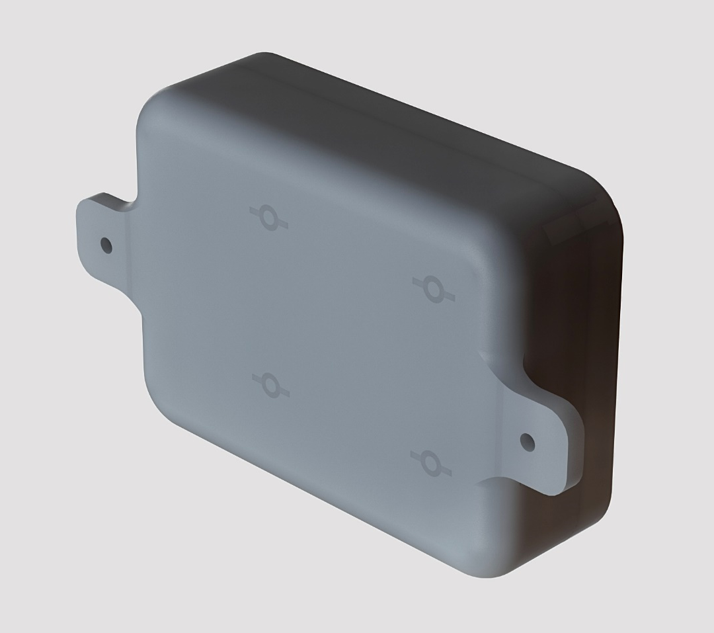
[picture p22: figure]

Рис. 9 – Вид сзади.

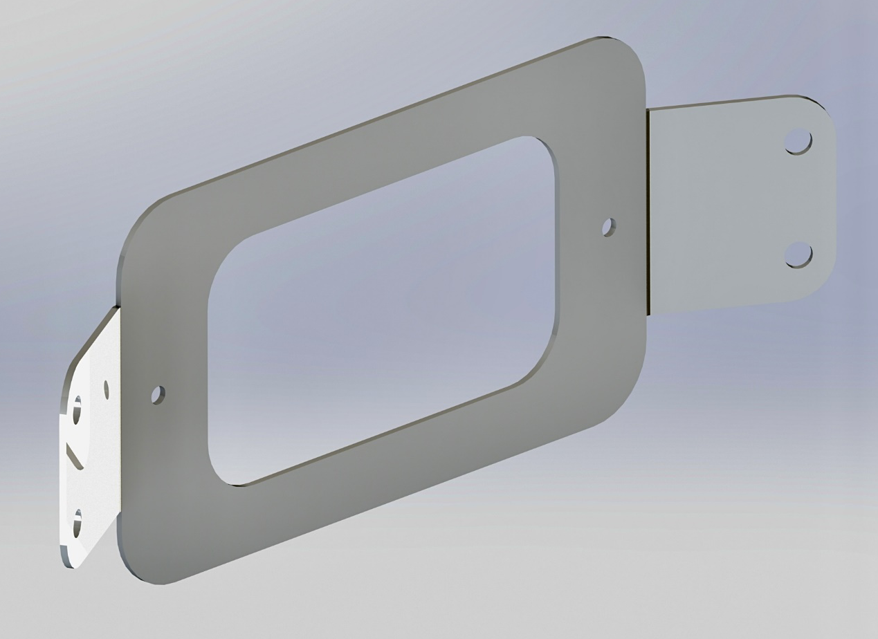
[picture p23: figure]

Рис. 10 – Вид изометрия металлического крепления.

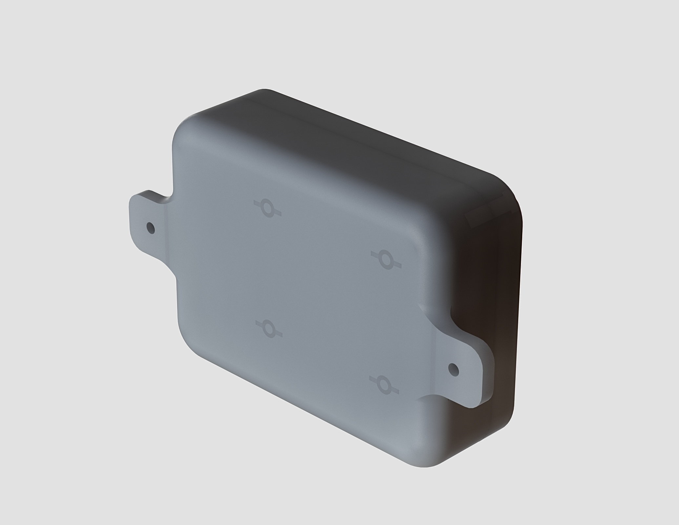
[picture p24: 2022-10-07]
Hardware_fabrication/Tracker/v2.0 19.03.2022/3d/Скриншоты/IMG_4818.JPG

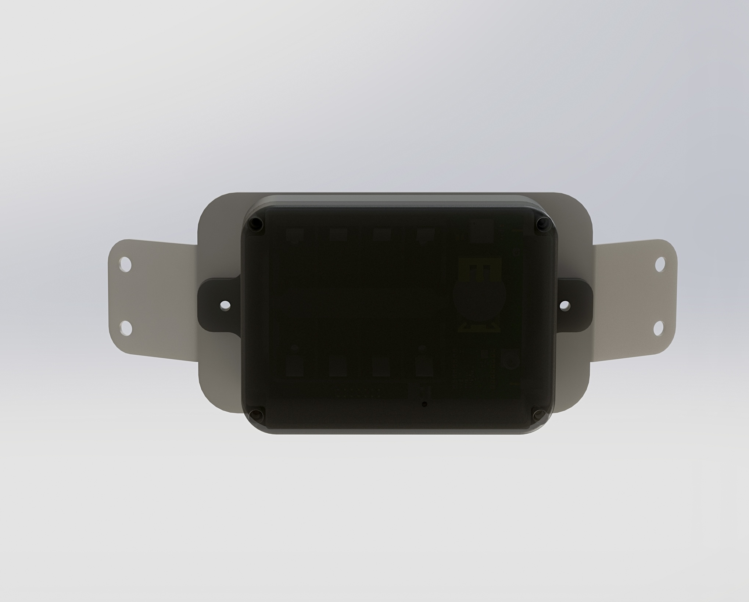
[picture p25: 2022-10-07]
Hardware_fabrication/Tracker/v2.0 19.03.2022/3d/Скриншоты/IMG_4816.JPG

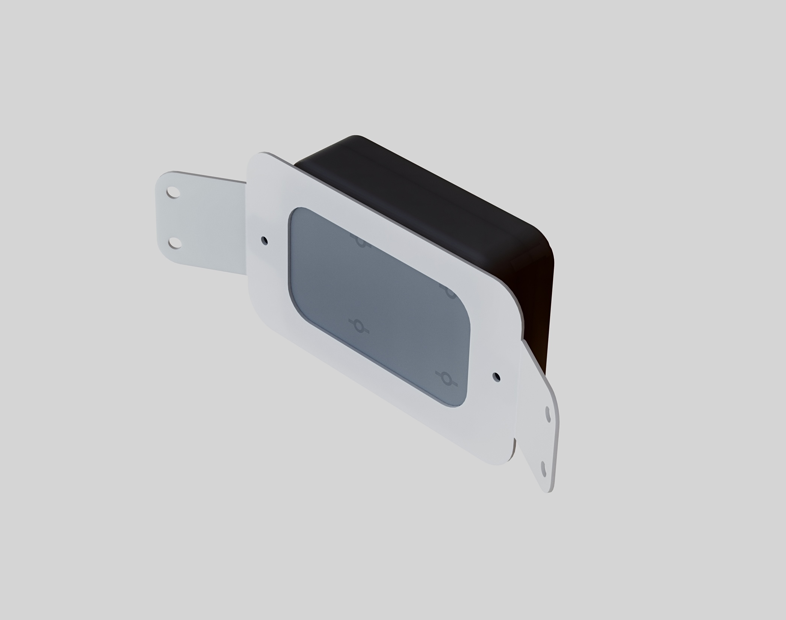
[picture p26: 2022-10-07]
Hardware_fabrication/Tracker/v2.0 19.03.2022/3d/Скриншоты/IMG_4815.JPG

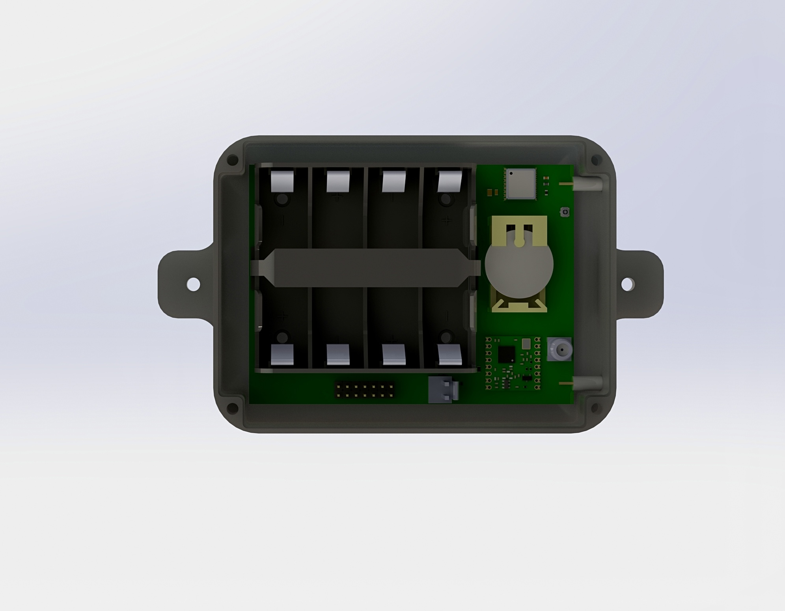
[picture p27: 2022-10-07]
Hardware_fabrication/Tracker/v2.0 19.03.2022/3d/Скриншоты/IMG_4817.JPG

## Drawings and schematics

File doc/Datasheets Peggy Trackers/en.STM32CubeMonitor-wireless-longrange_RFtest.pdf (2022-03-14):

# STM32CubeMonitor

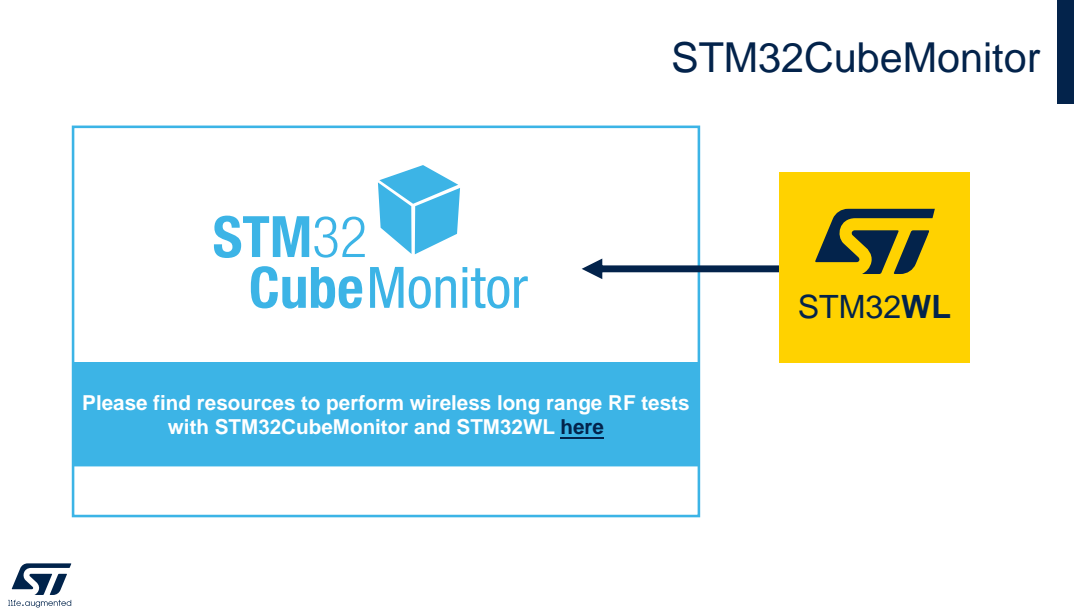
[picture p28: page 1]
STM32WL

Please find resources to perform wireless long range RF tests

with STM32CubeMonitor and STM32WL here (https://wiki.st.com/stm32mcu/wiki/STM32CubeMonitor:Wireless_Long_Range_RF_Test)

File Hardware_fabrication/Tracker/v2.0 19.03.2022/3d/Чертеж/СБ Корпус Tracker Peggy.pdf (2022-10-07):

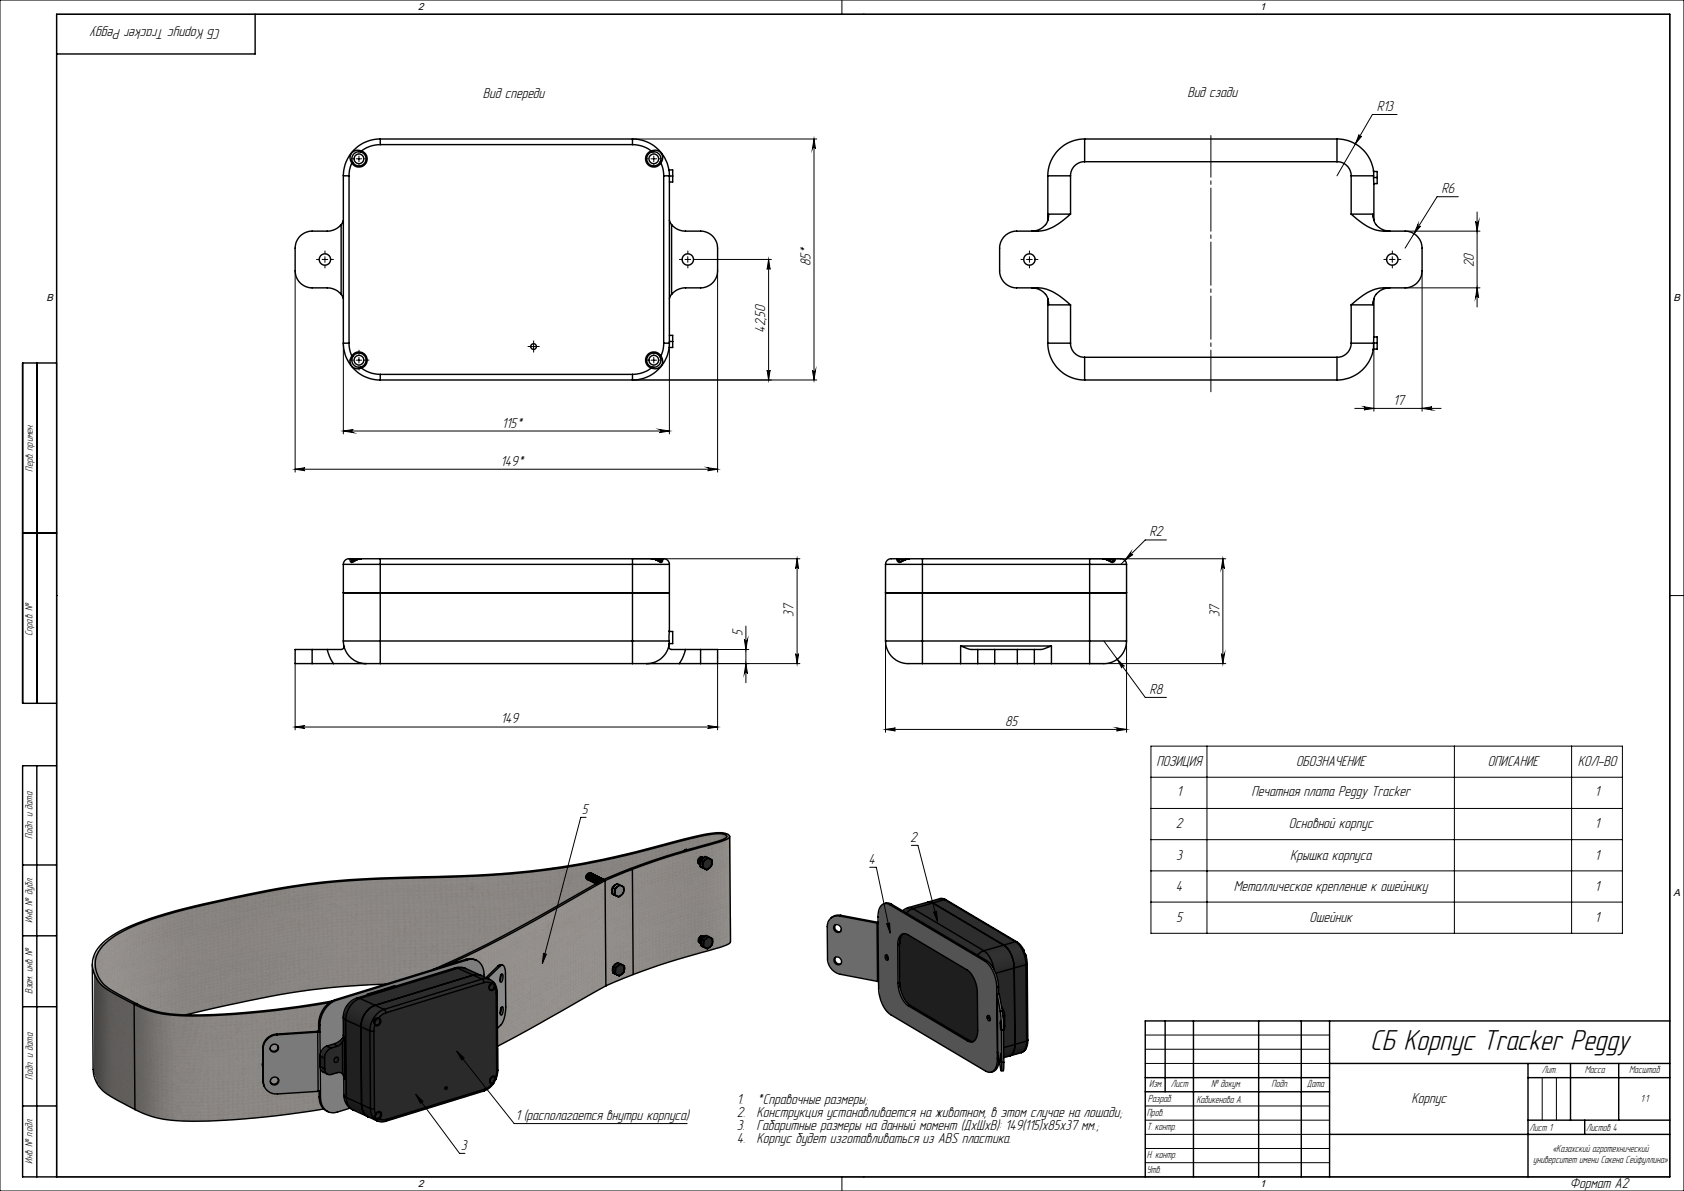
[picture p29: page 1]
Âèä ñïåðåäè; Ôîðìàò À2

Âèä ñçàäè
4. Êîðïóñ áóäåò èçãîòàâëèâàòüñÿ èç ABS ïëàñòèêà. 85*

Ñïðàâ. ¹ Ïåðâ. ïðèìåí. Ïîäï. è äàòà Èíâ. ¹ äóáë. Âçàì. èíâ. ¹ Ïîäï. è äàòà Èíâ. ¹ ïîäë.

ÏÎÇÈÖÈß | ÎÁÎÇÍÀ×ÅÍÈÅ | ÎÏÈÑÀÍÈÅ | ÊÎË-ÂÎ

1 | Ïå÷àòíàÿ ïëàòà Peggy Tracker | | 1

2 | Îñíîâíîé êîðïóñ | | 1

3 | Êðûøêà êîðïóñà | | 1

4 | Ìåòàëëè÷åñêîå êðåïëåíèå ê îøåéíèêó | | 1

5 | Îøåéíèê | | 1

ÑÁ Êîðïóñ Tracker Peggy

Êîðïóñ | Ëèò. | Ìàññà | Ìàñøòàá

Èçì. | Ëèñò | ¹ äîêóì. | Ïîäï. | Äàòà | | | | | 1:1
Ðàçðàá. | | Êàáèêåíîâà À.
Ïðîâ.
Ò. êîíòð. | | | | | Ëèñò 1 | Ëèñòîâ 4

1. *Ñïðàâî÷íûå ðàçìåðû;
2. Êîíñòðóêöèÿ óñòàíàâëèâàåòñÿ íà æèâîòíîì, â ýòîì ñëó÷àå íà ëîøàäè;
3. Ãàáàðèòíûå ðàçìåðû íà äàííûé ìîìåíò (ÄõØõÂ): 149(115)õ85õ37 ìì.;

1 (ðàñïîëàãàåòñÿ âíóòðè êîðïóñà)

«Êàçàõñêèé àãðîòåõíè÷åñêèé óíèâåðñèòåò èìåíè Ñàêåíà Ñåéôóëëèíà»

Í. êîíòð.
Óòâ.

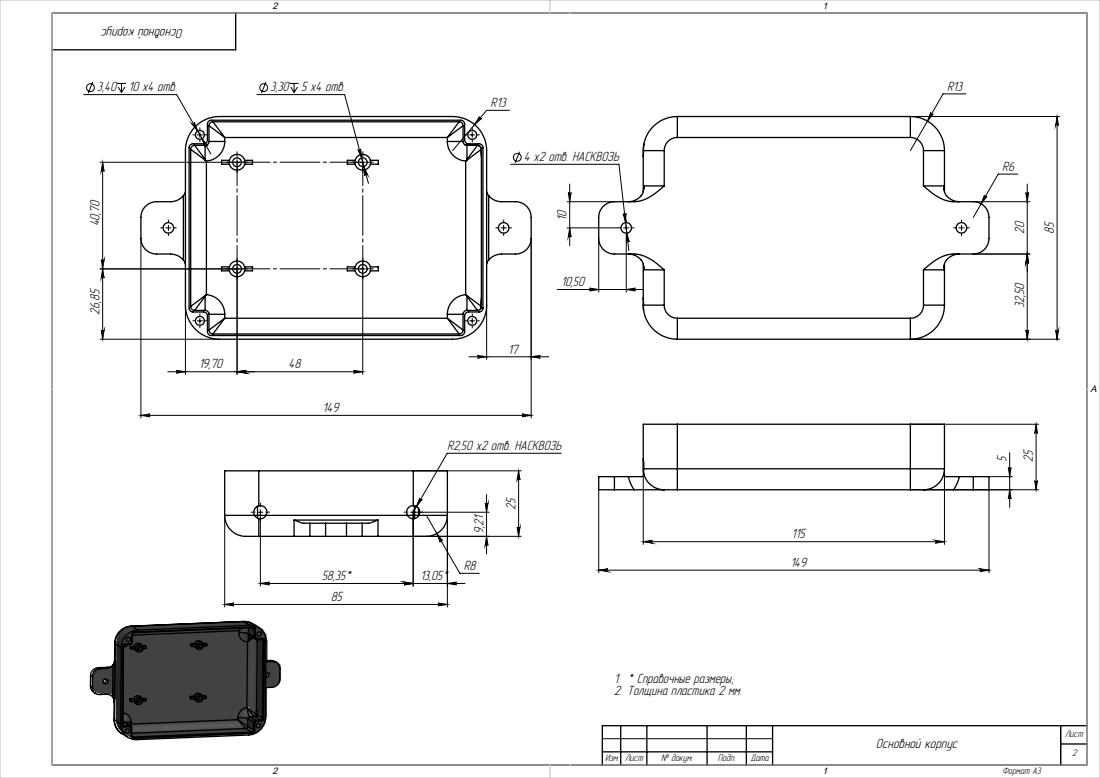
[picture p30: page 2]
3,40 10 õ4 îòâ.; 3,30 5 õ4 îòâ.; 4 õ2 îòâ. ÍÀÑÊÂÎÇÜ 10; R2,50 õ2 îòâ. ÍÀÑÊÂÎÇÜ; ¹ äîêóì.; Ïîäï.; Äàòà; Îñíîâíîé êîðïóñ

1. * Ñïðàâî÷íûå ðàçìåðû;
2. Òîëùèíà ïëàñòèêà 2 ìì.

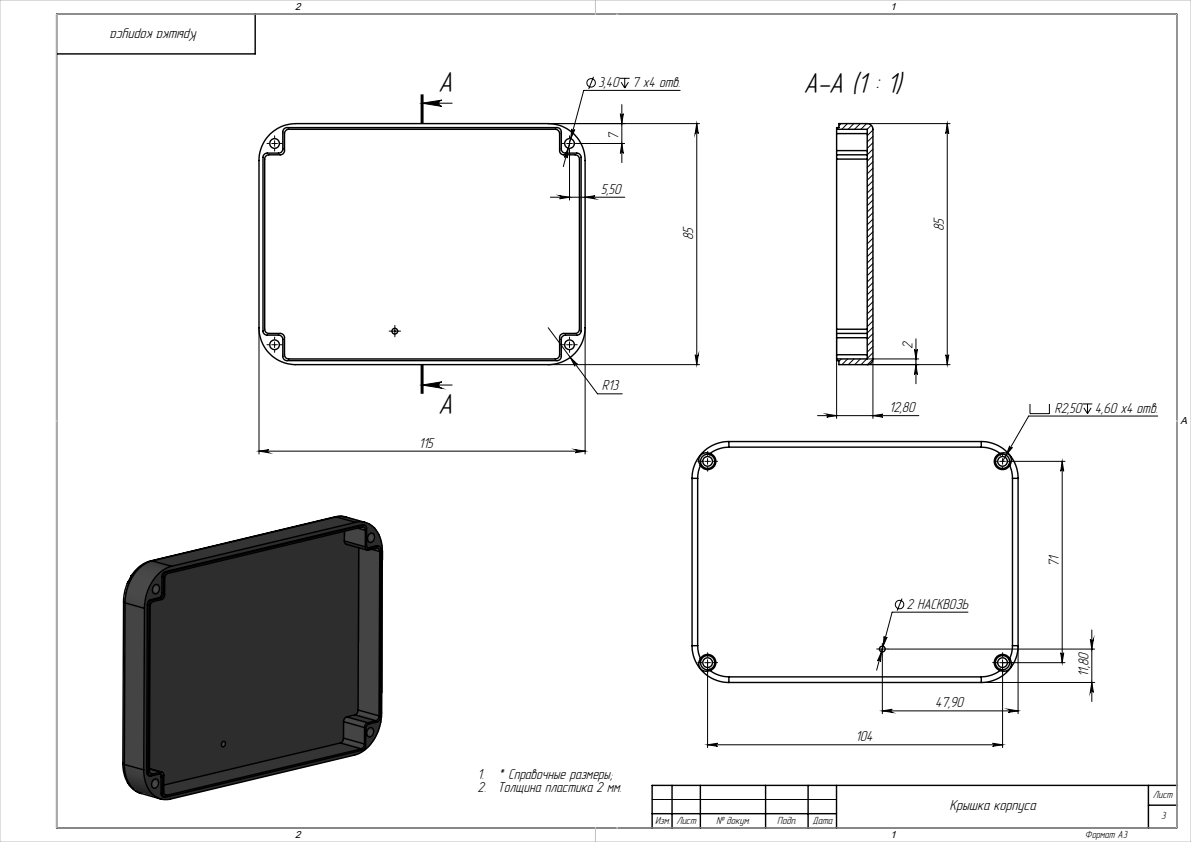
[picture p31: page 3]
3,40 7 õ4 îòâ.; 2 ÍÀÑÊÂÎÇÜ; R2,50 4,60 õ4 îòâ.; ¹ äîêóì.; Ïîäï.; Äàòà; Êðûøêà êîðïóñà

1. * Ñïðàâî÷íûå ðàçìåðû;
2. Òîëùèíà ïëàñòèêà 2 ìì.

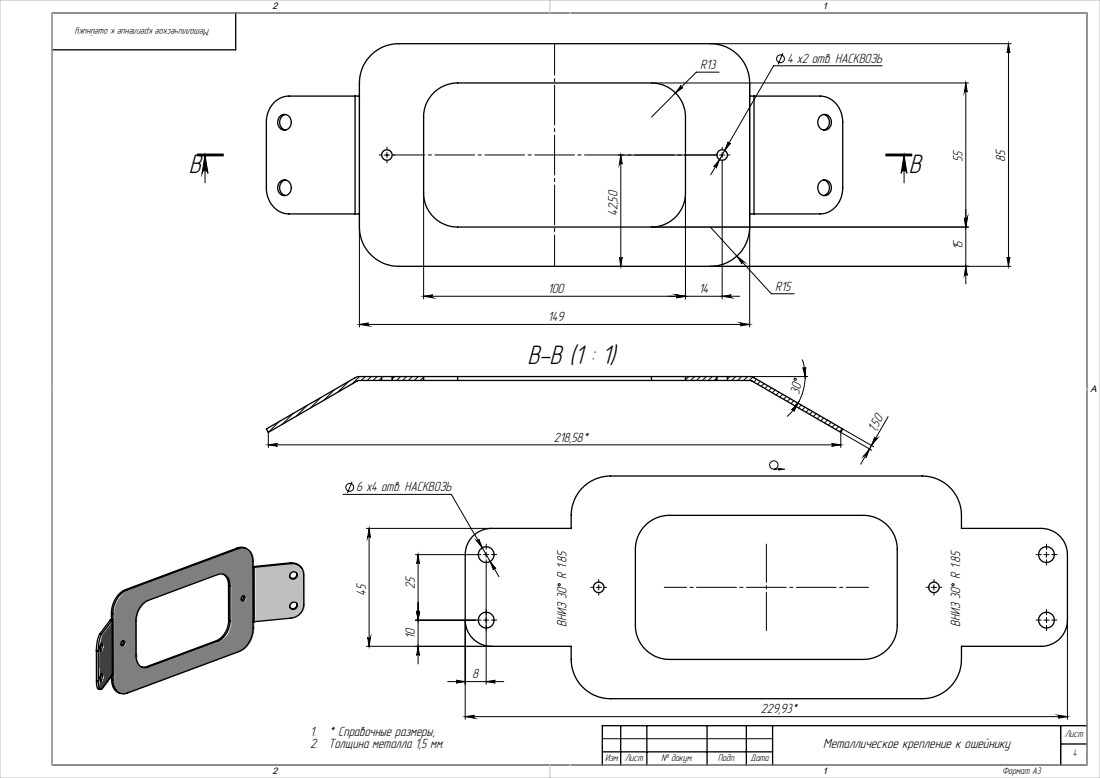
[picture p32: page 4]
4 õ2 îòâ. ÍÀÑÊÂÎÇÜ; 6 õ4 îòâ. ÍÀÑÊÂÎÇÜ; ÂÍÈÇ 30 R 1.85; ¹ äîêóì.; Ïîäï.; Äàòà

1. * Ñïðàâî÷íûå ðàçìåðû;
2. Òîëùèíà ìåòàëëà 1,5 ìì.

Ìåòàëëè÷åñêîå êðåïëåíèå ê îøåéíèêó

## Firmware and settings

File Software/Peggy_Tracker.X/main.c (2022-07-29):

/*
 * @file: main.c
 * @author: Jedi
 * @date 27 декабря 2021 г., 19:03
 */
#define F_CPU 8000000UL

#include "main.h"
#include "timer0.h"
#include "gpio.h"
#include <avr/interrupt.h>
#include <util/delay.h>
#include "uart.h"
#include "lora.h"
#include "string.h"

#include "avr/wdt.h"

volatile unsigned char acquisition_completed = 0;
volatile unsigned char rx_done = 0;
volatile unsigned char t0_compa_number;

/**
 * @brief Точка входа в программу
 */
int main(void) {
#define EMULATOR    
#ifdef EMULATOR
    uint32_t count = 0;
#endif

    cli();
    wdt_reset();
    wdt_enable(WDTO_250MS);

    led_init();

    lora_init();
    
    t0_compa_number = 0;
    t0_ctc_start(3, 124); ///< Запуск таймера с периодом 1мс

    wdt_enable(WDTO_60MS);
    sei();

    while (1) {
	wdt_reset();
    }
    return 0;
}

/**
 * @brief Обработчик прерываний переполнения таймера 0 производит опрос 
 * входных сигналов каждую 1мс. По прошествии 150мс счетчик милисекунд 
 * обнуляется, поднимается флаг о готовности к фильтрации. 
 */
ISR(TIMER0_COMPA_vect) {
}

/**
 * @brief Прерывание вызывается при получении сигнала по LoRa.
 * Таймер 0 останавливается. Устанавливается программный флаг получения по Lora
 */
ISR(INT6_vect) {
    rx_done = 1;
}

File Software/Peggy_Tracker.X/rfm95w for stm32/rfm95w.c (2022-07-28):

/*
 * rfm95w.c
 *
 *  Created on: Aug 8, 2019
 *      Author: Baiguanysh Sanat
 *  Библиотека для управления LoRa модуля RFM95W / SX1278 / HPD13
 *
 *  Для работы библиотеки необходим настроенный интерфейс SPI:
 *  	Mode: full-duplex Master
 *  	Hardware NSS: disable
 *  	Frame Format: Motorola
 *  	Data Size: 8 bits
 *  	First bit: MSB
 *  	Prescaler 4
 *  	Baud Rate: 2.0MBits/s
 *  	CPOL: Low
 *  	CPHA: 1 Edge
 *  	CRC: Disabled
 *  	NSS: Software
 *
 * Параметры режима передачи данных:
 * 	режим передачи: continuous
 *
 */

#include "rfm95w.h"

// registers
#define REG_FIFO                	0x00
#define REG_OP_MODE 				0x01
#define REG_FRF_MSB             	0x06
#define REG_FRF_MID             	0x07
#define REG_FRF_LSB             	0x08
#define REG_PA_CONFIG            	0x09
#define REG_LNA                  	0x0c
#define REG_FIFO_ADDR_PTR        	0x0d
#define REG_FIFO_TX_BASE_ADDR    	0x0e
#define REG_FIFO_RX_BASE_ADDR    	0x0f
#define REG_FIFO_RX_CURRENT_ADDR 	0x10
#define REG_IRQ_FLAGS_MASK			0x11
#define REG_IRQ_FLAGS            	0x12
#define REG_RX_NB_BYTES          	0x13
#define REG_PKT_RSSI_VALUE       	0x1a
#define REG_PKT_SNR_VALUE        	0x1b
#define REG_MODEM_CONFIG_1       	0x1d
#define REG_MODEM_CONFIG_2       	0x1e
#define REG_PREAMBLE_MSB         	0x20
#define REG_PREAMBLE_LSB         	0x21
#define REG_PAYLOAD_LENGTH       	0x22
#define REG_MODEM_CONFIG_3       	0x26
#define REG_RSSI_WIDEBAND        	0x2c
#define REG_DETECTION_OPTIMIZE   	0x31
#define REG_DETECTION_THRESHOLD  	0x37
#define REG_SYNC_WORD            	0x39
#define REG_DIO_MAPPING_1        	0x40
#define REG_VERSION              	0x42

// modes
#define MODE_LONG_RANGE_MODE     	0x80
#define MODE_SLEEP               	0x00
#define MODE_STDBY               	0x01
#define MODE_FSTX					0x02
#define MODE_TX                  	0x03
#define MODE_FSRX					0x04
#define MODE_RX_CONTINUOUS       	0x05
#define MODE_RX_SINGLE           	0x06
#define MODE_CAD					0x07

// PA config
#define PA_BOOST                 	0x80
#define RFO                      	0x70

// IRQ masks
#define IRQ_RX_TIMEOUT_MASK			0x80
#define IRQ_RX_DONE_MASK			0x40
#define IRQ_CRC_CHECK_ERROR_MASK	0x20
#define IRQ_VALID_HEADER_MASK		0x10
#define IRQ_TX_DONE_MASK           	0x08
#define IRQ_CAD_DONE_MASK			0x04
#define IRQ_FHSS_CHCH_MASK			0x02
#define IRQ_CAD_DETECTED_MASK		0x01

#define MAX_PKT_LENGTH           	255

/*
 * Прототипы приватных функций библиотеки
 */


void freqSet(long frequency);
void txPowerSet(int level, int outputPin);
void signalBandwidthSet(long sbw);
int8_t codingRateSet4(uint8_t denominator);
int8_t spreadingFactorSet(uint8_t sf);
void csHigh();
void csLow();
void rstHigh();
void rstLow();
void implicitHeaderMode();
void explicitHeaderMode();
int payloadAvailable();
int readPayload();
uint8_t clearIrq(uint8_t irq);
void modeSleep();
int8_t preambleSet(unsigned long length);

/*
 *
 *
 * Локальные функции
 *
 *
 */
void csHigh() {
	HAL_GPIO_WritePin(lora.nss_port, lora.nss_pin, GPIO_PIN_SET);
}

void csLow() {
	HAL_GPIO_WritePin(lora.nss_port, lora.nss_pin, GPIO_PIN_RESET);
}

void rstHigh() {
	HAL_GPIO_WritePin(lora.rst_port, lora.rst_pin, GPIO_PIN_SET);
}

void rstLow() {
	HAL_GPIO_WritePin(lora.rst_port, lora.rst_pin, GPIO_PIN_RESET);
}

void modeSleep() {
	regWr(REG_OP_MODE, MODE_LONG_RANGE_MODE | MODE_SLEEP);
}

void modeStandby() {
	regWr(REG_OP_MODE, MODE_LONG_RANGE_MODE | MODE_STDBY);
}

uint8_t regRd(uint8_t addr) {
	uint8_t txd = addr & 0x7f;
	uint8_t rxd[2] = { 0 };

	csLow();
	HAL_SPI_TransmitReceive((SPI_HandleTypeDef*) lora.spi, &txd, &rxd[0],
			sizeof(rxd[0]), 0x1000);
	txd = 0x00;
	HAL_SPI_TransmitReceive((SPI_HandleTypeDef*) lora.spi, &txd, &rxd[1],
			sizeof(rxd[1]), 0x1000);
	csHigh();

	return rxd[1];
}

void regWr(uint8_t addr, uint8_t val) {
	uint8_t txd = addr | 0x80;

	csLow();
	HAL_SPI_Transmit((SPI_HandleTypeDef*) lora.spi, &txd, sizeof(txd), 0x1000);
	HAL_SPI_Transmit((SPI_HandleTypeDef*) lora.spi, &val, sizeof(txd), 0x1000);
	csHigh();
}

void freqSet(long frequency) {
	uint64_t frf = ((uint64_t) frequency << 19) / 32000000;
	regWr(REG_FRF_MSB, (uint8_t) (frf >> 16));
	regWr(REG_FRF_MID, (uint8_t) (frf >> 8));
	regWr(REG_FRF_LSB, (uint8_t) (frf >> 0));
}

void txPowerSet(int level, int outputPin) {
	if (PA_OUTPUT_RFO_PIN == outputPin) {
// RF0
		if (level < 0) {
			level = 0;
		} else if (level > 14) {
			level = 14;
		}
		regWr(REG_PA_CONFIG, RFO | (level + 1));
	} else {
// PA BOOST
		if (level < 2) {
			level = 2;
		} else if (level > 17) {
			level = 17;
		}
		regWr(REG_PA_CONFIG, PA_BOOST | (level - 2));
	}
}

int8_t codingRateSet4(uint8_t denominator) {
	if (denominator < 5) {
		denominator = 5;
	} else if (denominator > 8) {
		denominator = 8;
	}
	int cr = denominator - 4;
	regWr(REG_MODEM_CONFIG_1, (regRd(REG_MODEM_CONFIG_1) & 0xf1) | (cr << 1));
	return 0;
}

int8_t spreadingFactorSet(uint8_t sf) {
	if (sf < 6) {
		sf = 6;
	} else if (sf > 12) {
		sf = 12;
	}
	if (sf == 6) {
		regWr(REG_DETECTION_OPTIMIZE, 0xc5);
		regWr(REG_DETECTION_THRESHOLD, 0x0c);
	} else {
		regWr(REG_DETECTION_OPTIMIZE, 0xc3);
		regWr(REG_DETECTION_THRESHOLD, 0x0a);
	}
	regWr(REG_MODEM_CONFIG_2,
			(regRd(REG_MODEM_CONFIG_2) & 0x0f) | ((sf << 4) & 0xf0));
	return 0;
}

int8_t preambleSet(unsigned long length) {
	regWr(REG_PREAMBLE_MSB, (uint8_t) (length >> 8));
	regWr(REG_PREAMBLE_LSB, (uint8_t) (length >> 0));
	return 0;
}

void signalBandwidthSet(long sbw) {
	int bw;
	if (sbw <= 7.8E3) {
		bw = 0;
	} else if (sbw <= 10.4E3) {
		bw = 1;
	} else if (sbw <= 15.6E3) {
		bw = 2;
	} else if (sbw <= 20.8E3) {
		bw = 3;
	} else if (sbw <= 31.25E3) {
		bw = 4;
	} else if (sbw <= 41.7E3) {
		bw = 5;
	} else if (sbw <= 62.5E3) {
		bw = 6;
	} else if (sbw <= 125E3) {
		bw = 7;
	} else if (sbw <= 250E3) {
		bw = 8;
	} else /*if (sbw <= 250E3)*/{
		bw = 9;
	}
	regWr(REG_MODEM_CONFIG_1, (regRd(REG_MODEM_CONFIG_1) & 0x0f) | (bw << 4));
}

uint8_t clearIrq(uint8_t irq) {
	regWr(REG_IRQ_FLAGS, irq);
	return regRd(REG_IRQ_FLAGS);
}

void implicitHeaderMode() {
	lora.implicitHeaderMode = 1;
	regWr(REG_MODEM_CONFIG_1, regRd(REG_MODEM_CONFIG_1) | 0x01);
}
void explicitHeaderMode() {
	lora.implicitHeaderMode = 0;
	regWr(REG_MODEM_CONFIG_1, regRd(REG_MODEM_CONFIG_1) & 0xfe);
}

int payloadAvailable() {
	return (regRd(REG_RX_NB_BYTES) - lora.pktIdx);
}

int readPayload() {
	if (!payloadAvailable()) {
		return -1;
	}
	lora.pktIdx++;
	return regRd(REG_FIFO);
}

/*
 *
 *
 * Public Functions
 *
 *
 *
 */
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

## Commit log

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2022-02-02 Объединил ПП и документацию в единый репозиторий
    [BOM 23.10.2021 17.42.xlsx, PCB1.PcbDoc, Peggy.PrjPcb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]
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2022-02-02 Перенес недостающие документы из облака в репозиторий
    [Сравнение систем связи для Peggy.xlsx]
2022-02-03 Поправил ридми и добавил гербер файлы трекера версии 1.0
    [BOM 23.10.2021 17.42.xlsx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]
2022-02-13 Добавил расчет предварительный расчет длительности работы АКБ в Peggy Tracker. Доработал структурную схему Peggy Tracker
    [Sheet1.SchDoc]
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2022-02-18 Загрузил план работ на 2022 год
    [План работ 2022 Peggy.xlsx]
2022-02-18 Добавил шелкографию у коннектора на плате
    [PCB1.PcbDoc, Sheet1.SchDoc]
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2022-02-19 Проверил требования к корпусу Peggy Repeater
    [Сравнение систем связи для Peggy.xlsx]
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2022-02-19 Все замечания исправлены.
2022-02-20 Сверил полученные посылки с BOM 20.02.2022
    [BOM 23.10.2021 17.42.xlsx]
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2022-02-20 Доработал структурную схему Peggy Receiver. Добавил обновлённую структурную схему в ТЗ
    [Принципиальная схема Peggy Tracker.SchDoc]
2022-03-14 Рефактор печатной платы v1.1
    [BOM 23.10.2021 17.42.xlsx, Peggy Receiver.PcbDoc, Peggy Receiver.PrjPcb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]
2022-03-15 Уточнил структурную схему Peggy Tracker. Добавил контакты для впаивания провода сигнализации
    [Печатная плата Peggy Tracker.PcbDoc, Принципиальная схема Peggy Tracker.SchDoc]
2022-03-18 Выгружены файлы для производства второй версии треккера
    [BOM v2.0 19.03.2022.xlsx, Peggy Tracker.PrjPcb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]
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2022-03-20 Выгрузил печатную плату Peggy Receiver v1.0
    [Peggy Receiver BOM v1.0 21.03.2022.xlsx, Peggy Receiver.PcbDoc, Peggy Receiver.PrjPcb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]
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2022-04-02 Объединил документы
    [План работ 2022 Peggy.xlsx, Сравнение систем связи для Peggy.xlsx]
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2022-05-01 Загружен примерный корпус трекера.
    [Case-01.SLDPRT, Case-02.SLDPRT]
2022-05-03 Изменил систему питания Peggy Tracker
    [BOM 23.10.2021 17.42.xlsx, BOM v2.0 19.03.2022.xlsx, Peggy Tracker.PrjPcb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]
2022-05-03 Peggy Tracker v3.0
    [BOM v3.0 03.05.2022.xlsx, Peggy Tracker.PrjPcb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]
2022-06-02 Изменен корпус.
    [Belt 3.SLDPRT, Belt mate 2.SLDPRT, Case-01.SLDPRT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]
2022-06-06 Минорные изменения
    [Peggy Tracker.PrjPcb, Принципиальная схема Peggy Tracker.SchDoc]
2022-06-09 Добавлена еще одна версия корпуса.
    [Case-01.SLDPRT, Case-02.SLDPRT, Case-03.SLDPRT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]
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2022-07-06 Начат подбор DC-DC
    [Peggy Tracker.PrjPcb, Принципиальная схема Peggy Tracker.SchDoc]
2022-07-10 Заменил питание, добавил tvs для петли
    [Принципиальная схема Peggy Tracker.SchDoc]
2022-07-10 изменения в схеме
    [Принципиальная схема Peggy Tracker.SchDoc]
2022-07-23 Заменена микросхема питания
    [Принципиальная схема Peggy Tracker.SchDoc]
2022-07-27 обвязка питания, замена холдера для батареи
    [Принципиальная схема Peggy Tracker.SchDoc]
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2022-07-28 добавлены МК, радиомодуль
    [Peggy Tracker.PrjPcb, Схема блока МК Peggy Tracker.SchDoc]
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2022-07-30 закончены соединения МК, GPS, lora
    [Peggy Tracker.PrjPcb, Принципиальная схема Peggy Tracker.SchDoc, Схема блока МК Peggy Tracker.SchDoc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]
2022-07-31 Добавил RTC
    [Схема блока МК Peggy Tracker.SchDoc, Схема питания и GPS Peggy Tracker.SchDoc]
2022-07-31 Схема закончена
    [Peggy Tracker.PrjPcb, Схема блока МК Peggy Tracker.SchDoc, Схема питания и GPS Peggy Tracker.SchDoc]
2022-08-01 Сгенерировал BOM
    [Peggy Tracker v5 BOM.xlsx, Peggy Tracker.PrjPcb, Схема блока МК Peggy Tracker.SchDoc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]
2022-08-04 Отрисованы в 3д 2 антенны.
    [Антенна CRJKS0010-LNA-G65U.SLDPRT, Антенна MIKE3A.SLDPRT]
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2022-08-17 перенос некоторых компонентов в локальные библиотеки (из-за нестабильной работы конкорда удаленно)
    [Peggy Tracker.PrjPcb, Схема блока МК Peggy Tracker.SchDoc, Схема питания и GPS Peggy Tracker.SchDoc]
2022-08-18 решаю проблемы с отвалом футпринтов на плате
    [Схема блока МК Peggy Tracker.SchDoc, Схема питания и GPS Peggy Tracker.SchDoc]
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2022-08-23 Отрисован 2-ой отсек для батареек 18650, создана сборка примерная 3 версия корпуса.
    [Case-05.SLDPRT, Case-06.SLDPRT, Батарейный отсек 2 18650.SLDPRT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]
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2022-08-30 Добавил альтернативы для недостоющих компонентов в BOM
    [Peggy Tracker v5 BOM.xlsx]
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2022-09-05 Добавил гербер файлы и 3д модель платы
    [1-1123723-2.step.SLDPRT, 1.step.SLDASM, 2.step.SLDASM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]
2022-09-08 Сделана сборка корпуса с креплением.
    [Case-07.SLDPRT, Case-08.SLDPRT, Металлическое крепление к ошейнику_1.SLDPRT]
2022-10-02 Исправлены замечания по трассировке. Пересобраны гербера
    [PCBA Peggy Tracker v5 Gerber.GBL, PCBA Peggy Tracker v5 Gerber.GBO, PCBA Peggy Tracker v5 Gerber.GBP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]
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2022-10-07 Добавлен отчет по корпусам трекера.
    [Case-07.SLDPRT, Case-08.SLDPRT, Металлическое крепление к ошейнику_1.SLDPRT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]
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2022-11-29 закончил схему, сгенерировал бом, размещение компонентов
    [BOM Peggy Receiver.xlsx, Peggy Receiver.PrjPcb, Блок МК и радиомодуля Peggy Receiver.SchDoc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]
2022-12-06 изменил форму платы под корпус
    [1910.step, G1910.DXF, G1910.SLDPRT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]
2022-12-16 перетрассировка под новый корпус, создал гербера, обновил бом
    [BOM Peggy Receiver V2.xlsx, BOM Peggy Receiver.xlsx, Peggy Receiver.PrjPcb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]
2023-04-04 работа над 3д моделью трекера
    [1-1123723-2.step.SLDPRT, 1.step.SLDASM, 2.step.SLDASM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]
